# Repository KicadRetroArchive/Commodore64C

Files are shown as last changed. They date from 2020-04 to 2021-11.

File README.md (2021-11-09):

# Commodore 64C KiCad schematics

This project contains a series of schematics and PCB designs for the
Commodore 64C (aka C64-E) personal computer, redrawn in [KiCad](https://kicad.org/).

The schematic was extracted from images available from
[Bo Zimmerman's FTP site](http://www.zimmers.net/anonftp/pub/cbm/schematics/computers/c64/index.html).

The images are also available in the documentation directory.

The project is structured in three main folders:

- [250469-RevA](250469-RevA) - Revision A of the motherboard. This version is also known as
  _Short Board_ and sports the 64 pin _"Super PLA"_ (code 251715-01).
- [250469-RevB](250469-RevB) - Revision B of the motherboard. This version has
  a more advanced version of the Super PLA (code 252535-01) that integrates the Color RAM.
- [docs](docs) - Documentation.
- [libs](libs) - Project's specific KiCad libraries.

## References

- Schematics from [Zimmers FTP site](http://www.zimmers.net/anonftp/pub/cbm/schematics/computers/c64/index.html).
- [C64C Service Manual](http://www.zimmers.net/anonftp/pub/cbm/schematics/computers/c64/servicemanuals/C64-C64C_Service_Manual_314001-03_%281992_Mar%29.pdf).
- [Hardware information](https://www.c64-wiki.com/wiki/Portal:Hardware) from the C64-Wiki.

## Differences

While designing the schematics, I decided to consider the availability of all the
components used as a top priority. While there's little I can do for many of the
ICs, many other components can still be sourced from distributors today.

A few regular components are, however, impossible to find now. In these cases
I replaced them with the closest substitute I could find that is widely available.
These components are different from the originals:

- `CR2`: Diode Rectifier Bridge
- `L1`: Line Filter, 8 terminals
- `Y1`: Crystal
- `L3,L4`: RF Choke Coils
- Some transistors and diodes

## KiCad libraries

Both subprojects use two KiCad set of libraries:

- The [KiCad Retro Library](https://github.com/KicadRetroArchive/kicad-retro-library).
- Project-specific libraries located in the [libs](libs) directory.
  - `250469-01.lib` - C64C specific symbols.
  - `250469-01.pretty` - C64C specific footprints.

> The project-specific libraries are located in a directory **above** the actual
> KiCad project. They are referenced through the `KIPRJMOD` environment variable
> in this way: `"${KIPRJMOD}/../libs/<name of library>"`.

## Credits

This project has been heavily inspired by these awesome projects:

- [LittleSixteen](https://github.com/SukkoPera/LittleSixteen) - Clone of the Commodore 16 by [@SukkoPera](https://github.com/SukkoPera).
- [Commodore-Plus4](https://github.com/StormTrooper/Commodore-Plus4) - Clone of the Commodore Plus 4 by [@StormTrooper](https://github.com/StormTrooper).
- [KU-14194HB-RevB-KiCad](https://github.com/bwack/KU-14194HB-RevB-KiCad) - Clone of the Commodore 64, Assy KU-14194HB-RevB by [@bwack](https://github.com/bwack).

## Contributing

We gladly accept contributions via GitHub pull requests. Please see
[CONTRIBUTING.md](CONTRIBUTING.md) for more details.

## License

Original schematic drawings and service manual are &copy; Commodore Electronics Ltd.

All KiCad design files are copyright &copy; 2020 Andrea Cisternino.

This project is Open Hardware licensed under the
[CERN-OHL-S v2](https://ohwr.org/project/cernohl/wikis/Documents/CERN-OHL-version-2)
license.

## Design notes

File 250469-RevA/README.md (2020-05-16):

# Assembly 250469 Rev. A

Original board:

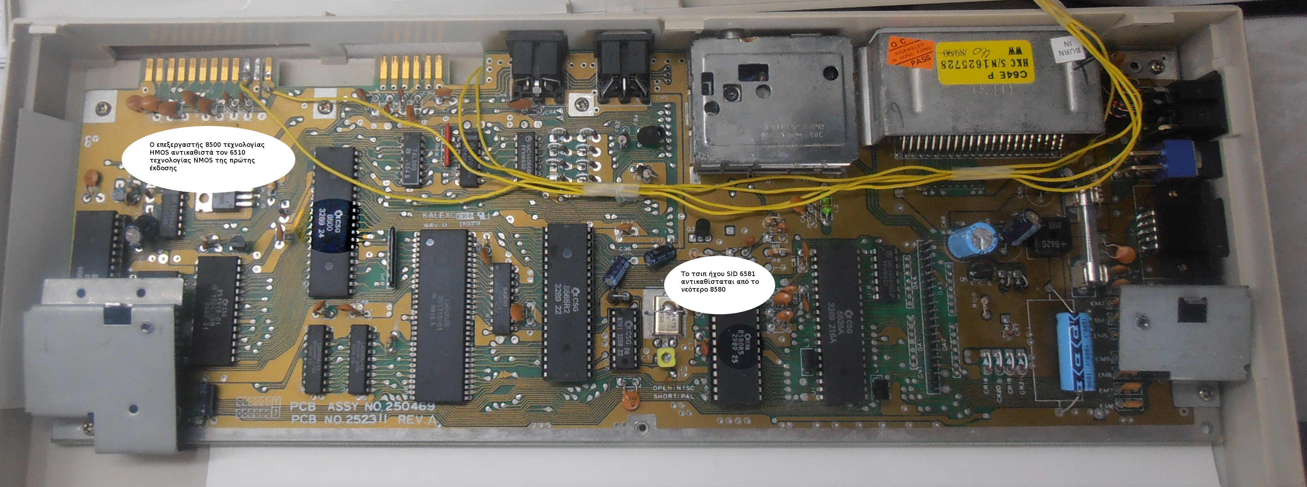
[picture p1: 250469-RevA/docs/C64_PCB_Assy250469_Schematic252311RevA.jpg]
250469 Rev. A board


(_From the [C64-Wiki](https://www.c64-wiki.com/wiki/Motherboard)_)

## Files

- Schematics in PDF: [C64C-250469-01-A.pdf](C64C-250469-01-A.pdf)
- Complete BOM in LibreOffice Calc format, including part numbers from Digi-Key and Mouser
  [C64C-250469-01-A.ods](C64C-250469-01-A.ods)

## Status

I am quite confident that the schematic is stable and bug-free.

**Good News!** I acquired a spare motherboard that matches exactly this revision.
With this example in my hand, I corrected all dimensional errors in the PCB.
I also placed with great precision all the external connectors.
Now work on routing the PCB can begin!

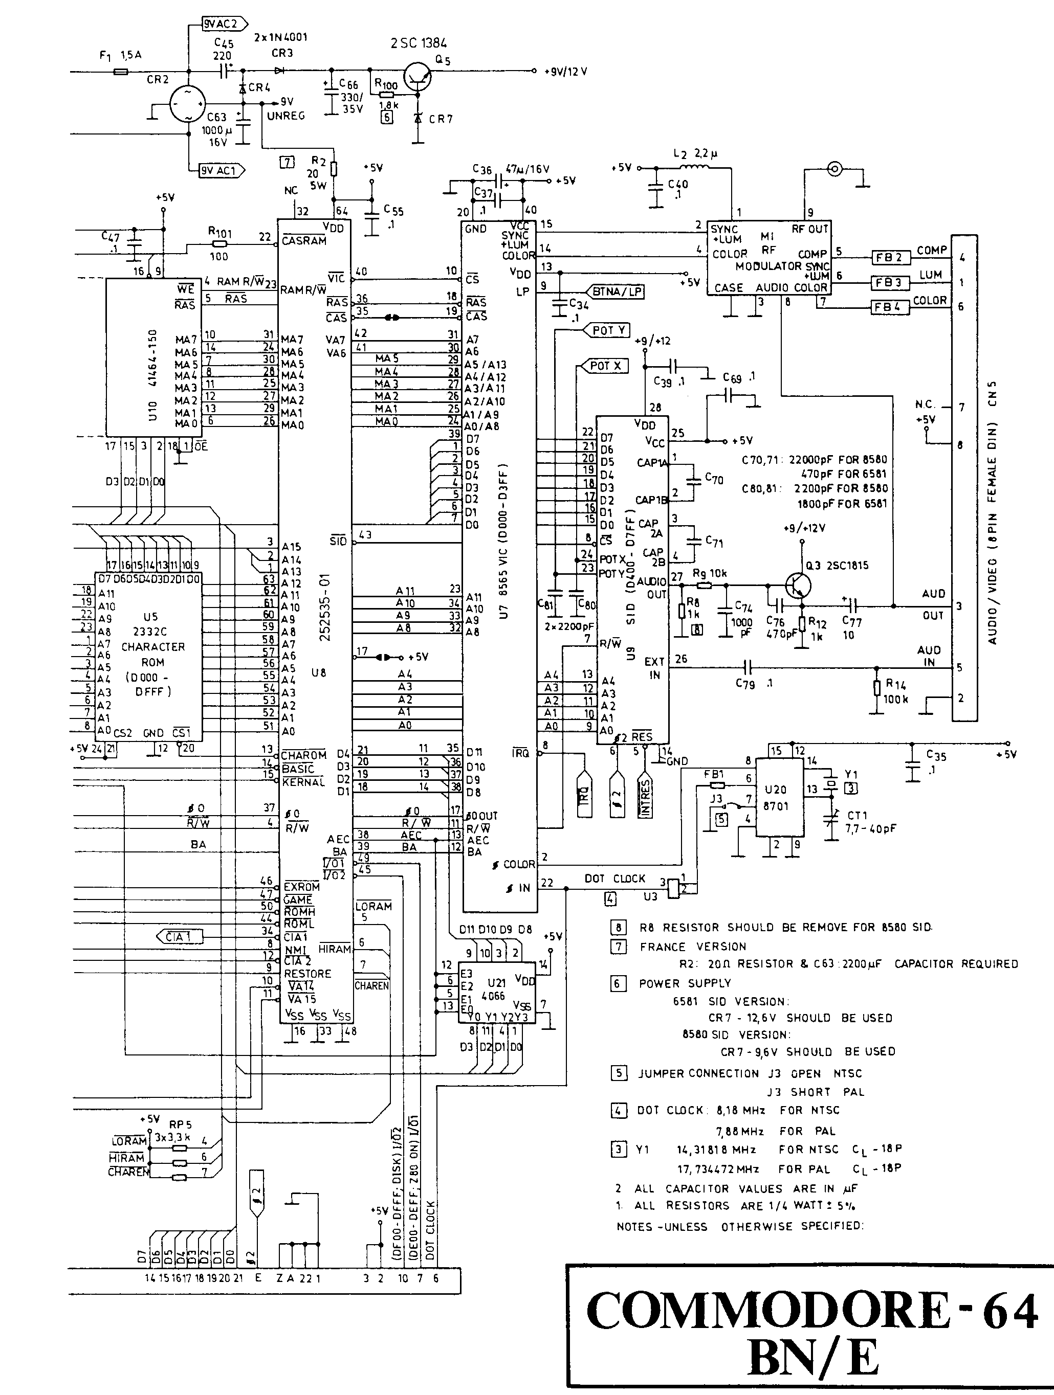
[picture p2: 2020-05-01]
docs/originals/250469-rev.B-right-corrected.png

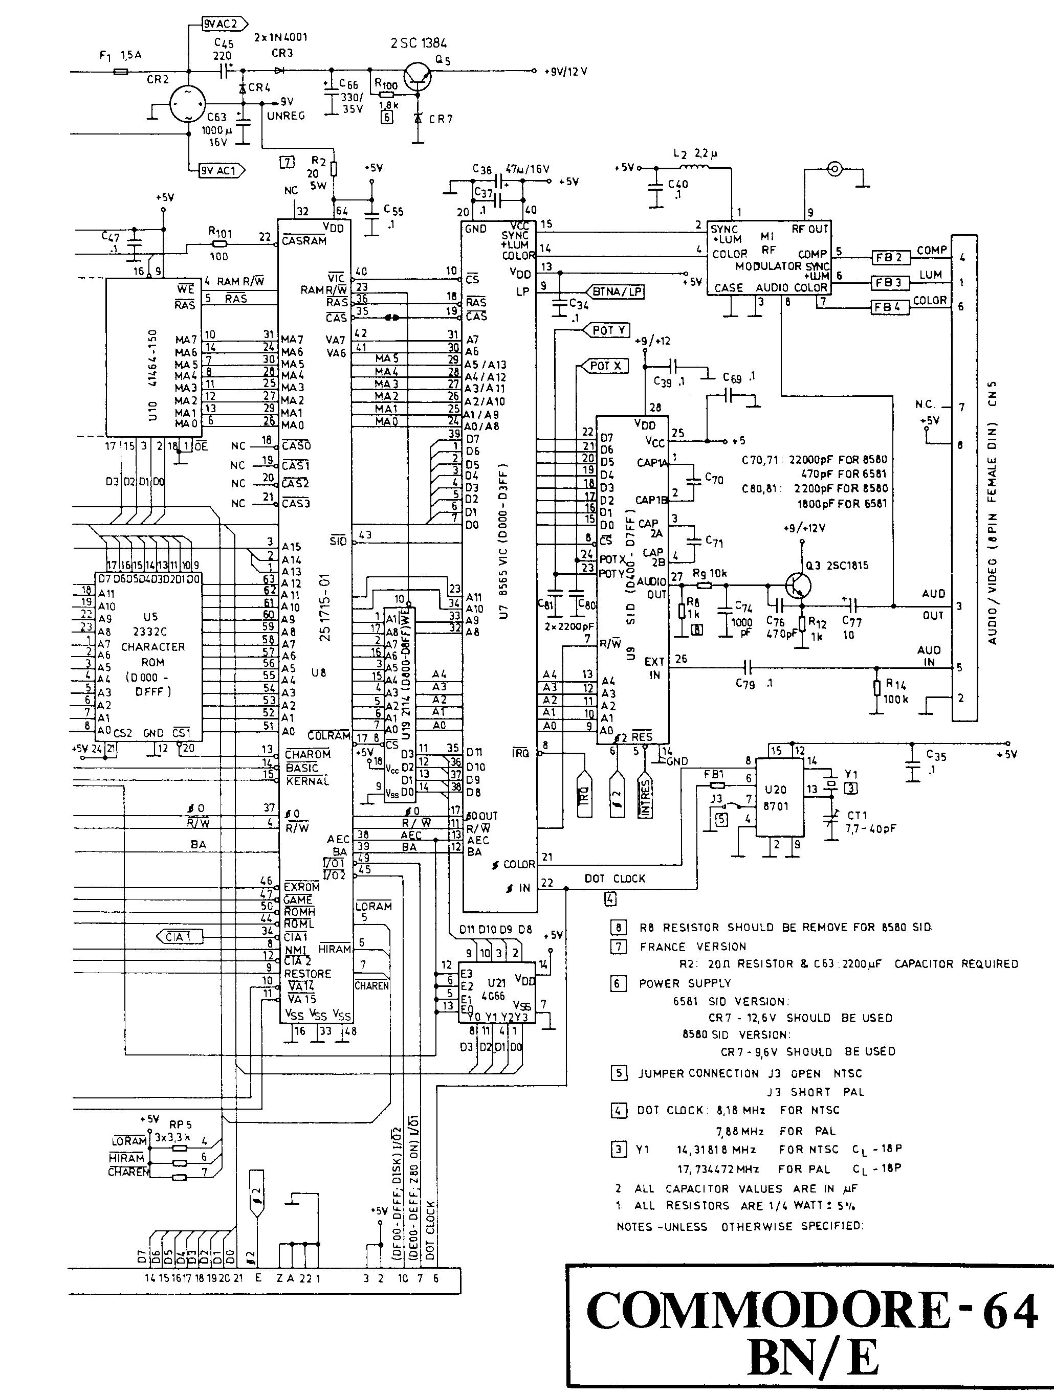
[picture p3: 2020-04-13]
docs/originals/250469-rev.A-right.png

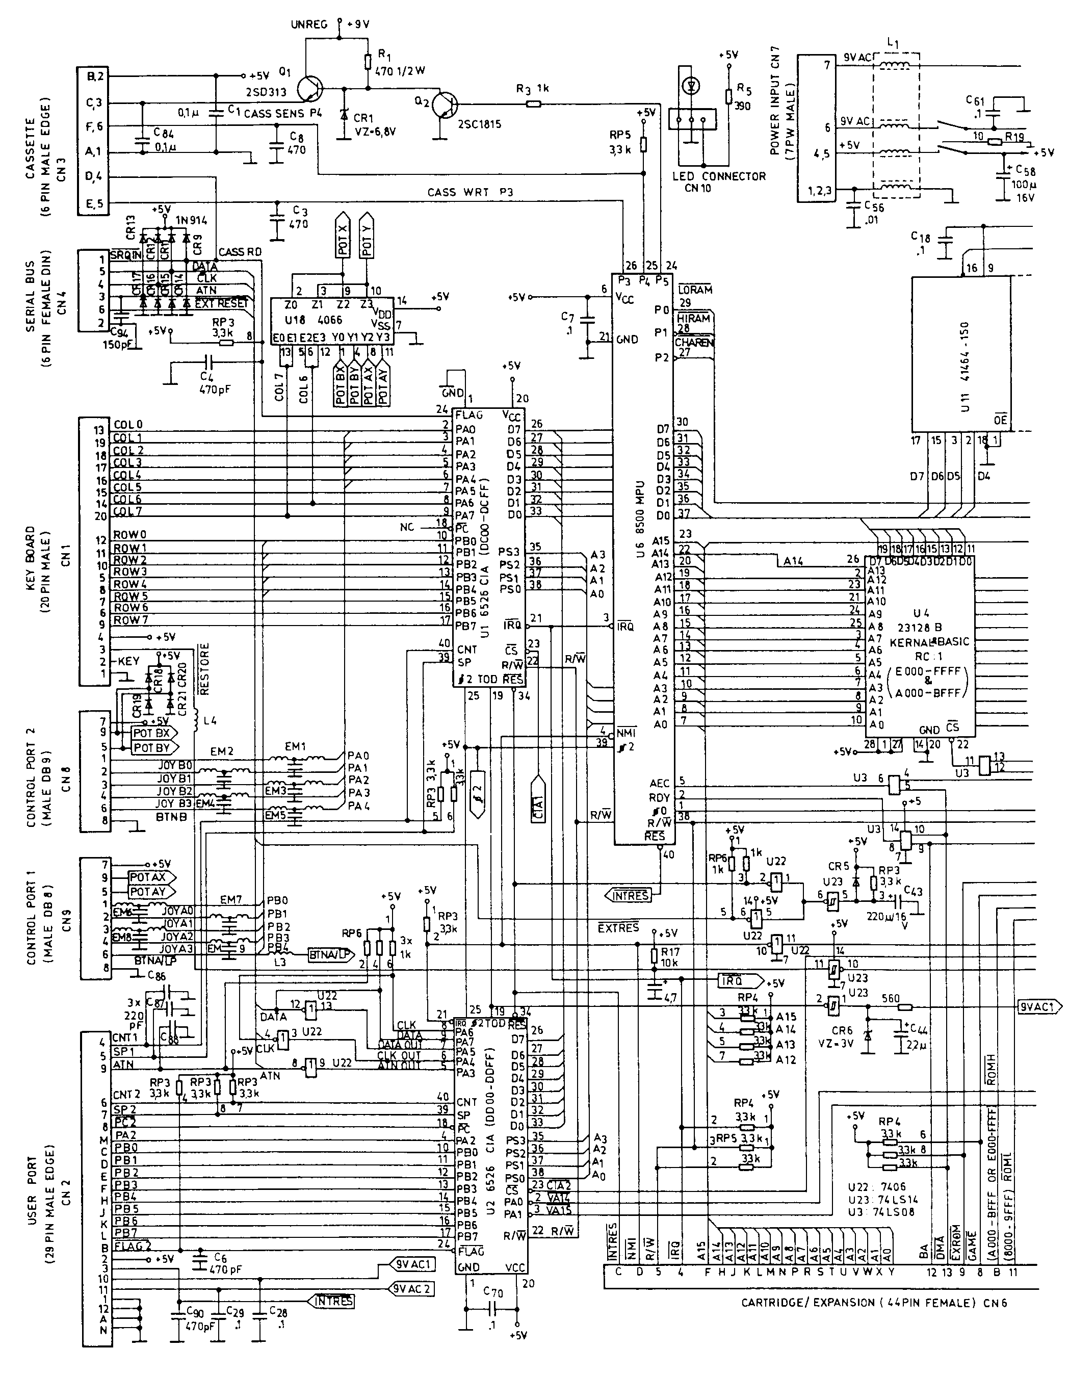
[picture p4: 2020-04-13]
docs/originals/250469-rev.A-left.png

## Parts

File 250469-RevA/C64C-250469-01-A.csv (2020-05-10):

Source: | /home/andrea/Development/github/Commodore64C/250469-RevA/C64C-250469-01-A.sch
Date: | Sun 10 May 2020 06:31:55 PM CEST
Tool: | Eeschema 5.1.5
Generator: | /home/andrea/Apps/kicad/plugins/bom_csv_sc_grouped_by_value_with_fp.py
Component Count: | 131
Ref | Qnty | Value | Cmp name | Footprint | Description | Vendor
C1, C7, C28, C29, C30, C34, C35, C37, C39, C40, C47, C48, C55, C56, C61, C69, C79, C84, | 18 | 0.1u | C | Capacitor_THT:C_Disc_D4.7mm_W2.5mm_P5.00mm | Unpolarized capacitor
C2, C3, C4, C6, C76, C90, | 6 | 470p | C | Capacitor_THT:C_Disc_D4.7mm_W2.5mm_P5.00mm | Unpolarized capacitor
C36, | 1 | 47u/16V | CP | Capacitor_THT:CP_Radial_D8.0mm_P5.00mm | Polarized capacitor
C43, | 1 | 220u | CP | Capacitor_THT:CP_Radial_D8.0mm_P5.00mm | Polarized capacitor
C44, | 1 | 2.2u | CP | Capacitor_THT:CP_Radial_D8.0mm_P5.00mm | Polarized capacitor
C58, | 1 | 100u/16V | CP | Capacitor_THT:CP_Radial_D10.0mm_P5.00mm | Polarized capacitor
C59, | 1 | 4.7u | CP | Capacitor_THT:CP_Radial_D8.0mm_P5.00mm | Polarized capacitor
C63, | 1 | 1000u/16V | CP | Capacitor_THT:CP_Axial_L30.0mm_D15.0mm_P35.00mm_Horizontal | Polarized capacitor
C65, | 1 | 220u | CP | Capacitor_THT:CP_Radial_D10.0mm_P5.00mm | Polarized capacitor
C66, | 1 | 330u/35V | CP | Capacitor_THT:CP_Radial_D12.5mm_P5.00mm | Polarized capacitor
C70, C71, | 2 | 22n | C | Capacitor_THT:C_Disc_D4.7mm_W2.5mm_P5.00mm | Unpolarized capacitor
C74, | 1 | 1000p | C | Capacitor_THT:C_Disc_D4.7mm_W2.5mm_P5.00mm | Unpolarized capacitor
C77, | 1 | 10u | CP | Capacitor_THT:CP_Radial_D10.0mm_P5.00mm | Polarized capacitor
C80, C81, | 2 | 2200p | C | Capacitor_THT:C_Disc_D4.7mm_W2.5mm_P5.00mm | Unpolarized capacitor
C86, C87, C88, | 3 | 220p | C | Capacitor_THT:C_Disc_D4.7mm_W2.5mm_P5.00mm | Unpolarized capacitor
C94, | 1 | 150p | C | Capacitor_THT:C_Disc_D4.7mm_W2.5mm_P5.00mm | Unpolarized capacitor
CB1, | 1 | SW_DPDT | SW_DPDT | 250469-01:RockerSwitch_CuK_DPDT_E201J1AV2 | Rocker Switch, dual pole double throw, on-on
CT1, | 1 | 7.7-40p | CTRIM | krl_Capacitor_THT:C_Trimmer_JML_JML06_P5mm | Trimmable capacitor
D1, | 1 | RD6.8EB | RD6.8EB | Diode_THT:D_DO-35_SOD27_P7.62mm_Horizontal | 500mW Zener Diode, 6.8V, DO-35
D2, | 1 | 2W02G-E4/51 | D_Bridge_+A-A | Diode_THT:Diode_Bridge_Round_D9.8mm | Diode bridge, +ve/AC/-ve/AC
D3, D4, | 2 | 1N4001 | 1N4001 | Diode_THT:D_DO-41_SOD81_P5.08mm_Vertical_KathodeUp | 50V 1A General Purpose Rectifier Diode, DO-41
D5, D9, D11, D12, D13, D14, D15, D16, D17, D18, D19, D20, D21, | 13 | 1N914 | 1N914 | Diode_THT:D_DO-35_SOD27_P5.08mm_Vertical_KathodeUp | 100V 0.3A Small Signal Fast Switching Diode, DO-35
D6, | 1 | RD3.0EB1 | RD3.0EB1 | Diode_THT:D_DO-35_SOD27_P5.08mm_Vertical_KathodeUp | 500mW Zener Diode, 3V, DO-35
D7, | 1 | RD10ESB2 | RD10ESB2 | Diode_THT:D_DO-34_SOD68_P5.08mm_Vertical_KathodeUp | 400mW Zener Diode, 10V, DO-34
F1, | 1 | 1.5A | Fuse | 250469-01:Fuseclip_Cylinder-6.3x32mm | Fuse
FB1, | 1 | 2 Turns | Ferrite_Bead | 250469-01:L_Axial_Dual_L7.0mm_D3.3mm_P5.08mm_Vertical | Ferrite bead
FB2, FB3, FB4, | 3 | Ferrite_Bead_Small | Ferrite_Bead_Small | Inductor_THT:L_Axial_L7.0mm_D3.3mm_P5.08mm_Vertical_Fastron_MICC | Ferrite bead, small symbol
FL1, FL2, FL3, FL4, FL5, FL6, FL7, FL8, FL9, | 9 | 270p | EMI_Filter_LCL | krl_Filter:LCL-Filter_2.8x8.5mm_P2.5mm | EMI T-filter (LCL)
J1, | 1 | Conn_01x20_Male | Conn_01x20_Male | Connector_PinHeader_2.54mm:PinHeader_1x20_P2.54mm_Vertical | Generic connector, single row, 01x20, script generated (kicad-library-utils/schlib/autogen/connector/)
J2, | 1 | Conn_02x12_Edge | Conn_02x12_Edge | 250469-01:Connector_Edge_2x12_P3.96mm | Edge connector, double side, 02x12
J3, | 1 | Conn_02x6_Edge | Conn_02x6_Edge | 250469-01:Connector_Edge_2x6_P3.96mm | Edge connector, double side, connected sides, 02x6
J4, | 1 | DIN-6 | DIN-6 | krl_Connector_DIN:CUI-Devices_SDS-60J_DIN-6_Circular | 6-pin DIN connector
J5, | 1 | DIN-8 | DIN-8 | krl_Connector_DIN:CUI-Devices_SDS-80J_DIN-8_Circular | 8-pin DIN connector
J6, | 1 | Conn_02x22_Edge_Female | Conn_02x22_Edge_Female | 250469-01:Sullins_EBC22DRAN | Generic connector, double row, 02x22, edge, female
J7, | 1 | DIN-7 | DIN-7 | krl_Connector_DIN:CUI-Devices_SDS-70J_DIN-7_Circular | 7-pin DIN connector
J8, J9, | 2 | DB9_Female | DB9_Female | 250469-01:Kycon_K22X-E9P-N_DSUB-9_Male_Horizontal | 9-pin female D-SUB connector
J10, | 1 | LED | Conn_01x03 | Connector_PinHeader_2.54mm:PinHeader_1x03_P2.54mm_Vertical | Generic connector, single row, 01x03, script generated (kicad-library-utils/schlib/autogen/connector/)
JP3, | 1 | Jumper | Jumper | Connector_PinHeader_2.54mm:PinHeader_1x02_P2.54mm_Vertical | Jumper, normally closed
L1, | 1 | CM4545Z131B-10 | CM4545Z131B-10 | krl_Filter:Laird_CM4545Z131B-10 | Quadruple Coupled inductor with ferrite core
L2, | 1 | 2.2u | L | Inductor_THT:L_Axial_L9.5mm_D4.0mm_P15.24mm_Horizontal_Fastron_SMCC | Inductor
L3, L4, | 2 | 10uH | L | 250469-01:L_Radial_L7.5mm_W3mm_P5.00mm_Kemet_SBT-02 | Inductor
M1, | 1 | RF_Modulator | RF_Modulator | 250469-01:RF_Modulator | C64C RF Modulator
Q1, | 1 | 2SD313 | 2SD313E | Package_TO_SOT_THT:TO-220-3_Horizontal_TabDown | 3A Ic, 60V Vce, High Voltage Power NPN Transistor, TO-220
Q2, Q3, | 2 | 2SC1815 | 2SC1815 | Package_TO_SOT_THT:TO-92_Inline | 0.15A Ic, 50V Vce, Low Noise Audio NPN Transistor, TO-92
Q5, | 1 | 2SC1384 | 2SC1384 | Package_TO_SOT_THT:TO-92_Inline | 1A Ic, 50V Vce, NPN Transistor, TO-92
R1, | 1 | 470 | R | Resistor_THT:R_Axial_DIN0309_L9.0mm_D3.2mm_P15.24mm_Horizontal | Resistor
R3, R8, R12, | 3 | 1k | R | Resistor_THT:R_Axial_DIN0207_L6.3mm_D2.5mm_P5.08mm_Vertical | Resistor
R5, | 1 | 390 | R | Resistor_THT:R_Axial_DIN0207_L6.3mm_D2.5mm_P5.08mm_Vertical | Resistor
R9, R17, | 2 | 10k | R | Resistor_THT:R_Axial_DIN0207_L6.3mm_D2.5mm_P5.08mm_Vertical | Resistor
R14, | 1 | 100k | R | Resistor_THT:R_Axial_DIN0207_L6.3mm_D2.5mm_P5.08mm_Vertical | Resistor
R16, | 1 | 560 | R | Resistor_THT:R_Axial_DIN0207_L6.3mm_D2.5mm_P5.08mm_Vertical | Resistor
R19, | 1 | 10 | R | Resistor_THT:R_Axial_DIN0309_L9.0mm_D3.2mm_P15.24mm_Horizontal | Resistor
R100, | 1 | 1.8k | R | Resistor_THT:R_Axial_DIN0207_L6.3mm_D2.5mm_P5.08mm_Vertical | Resistor
R101, | 1 | 100 | R | Resistor_THT:R_Axial_DIN0207_L6.3mm_D2.5mm_P5.08mm_Vertical | Resistor
RN3, RN5, | 2 | 3.3k | R_Network07 | Resistor_THT:R_Array_SIP8 | 7 resistor network, star topology, bussed resistors, small symbol
RN4, | 1 | 3.3k | R_Network08 | Resistor_THT:R_Array_SIP9 | 8 resistor network, star topology, bussed resistors, small symbol
RN6, | 1 | 1k | R_Network05 | Resistor_THT:R_Array_SIP6 | 5 resistor network, star topology, bussed resistors, small symbol
U1, U2, | 2 | 6526A | 6526A | Package_DIP:DIP-40_W15.24mm_Socket | CIA Complex Interface Adapter, NMOS, 2MHz, DIP-40
U3, | 1 | 74LS08 | 74LS08 | Package_DIP:DIP-14_W7.62mm_Socket | Quad And2
U4, | 1 | 23128 | 23128 | Package_DIP:DIP-28_W15.24mm_Socket | 16K x 8 Mask ROM, DIP-28
U5, | 1 | 2332 | 2332 | Package_DIP:DIP-24_W15.24mm_Socket | 4K x 8 Mask ROM, 450ns, DIP-24
U6, | 1 | 8500 | 8500 | Package_DIP:DIP-40_W15.24mm_Socket | CPU Central Processing Unit with I/O, 8-bit, HMOS, 1 MHz, DIP-40
U7, | 1 | 8565R2 | 8565R2 | Package_DIP:DIP-40_W15.24mm_Socket | VIC-II Video Interface Chip II, PAL, HMOS, DIP-40
U8, | 1 | 251715-01 | 251715-01 | krl_Package_SPDIP:SPDIP-64_W19.05mm_Socket_LongPads | C64C Memory Controller (SuperPLA), SPDIP-64
U9, | 1 | 8580R5 | 8580R5 | Package_DIP:DIP-28_W15.24mm_Socket | Video Interface Chip II - C64 - PAL, DIP-28
U10, U11, | 2 | 41464 | 41464 | Package_DIP:DIP-18_W7.62mm_Socket | 64K x 4 Dynamic NMOS RAM, DIP-18
U18, U21, | 2 | 4066 | 4066 | Package_DIP:DIP-14_W7.62mm_Socket | Quad Analog Switches
U19, | 1 | 2114 | 2114 | Package_DIP:DIP-18_W7.62mm_Socket | 1K x 4 Static RAM, DIP-18
U20, | 1 | 8701 | 8701 | Package_DIP:DIP-16_W7.62mm_Socket | C64 Clock Generator, DIP-16
U22, | 1 | 7416 | 7416 | Package_DIP:DIP-14_W7.62mm_Socket | TTL Hex inverter buffers/drivers with open-collector high-voltage outputs
U23, | 1 | 74LS14 | 74LS14 | Package_DIP:DIP-14_W7.62mm_Socket | Hex inverter schmitt trigger
Y1, | 1 | Crystal | Crystal | Crystal:Crystal_HC49-U_Vertical | Two pin crystal

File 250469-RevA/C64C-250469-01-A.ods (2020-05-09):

Ref | Qnty | Value | Cmp name | Footprint | Description | Vendor | MPM | DigiKey | Mouser
C1, C7, C28, C29, C30, C34, C35, C37, C39, C40, C47, C48, C55, C56, C61, C69, C79, C84, | 18 | 0.1u | C | Capacitor_THT:C_Disc_D4.7mm_W2.5mm_P5.00mm | Unpolarized capacitor | Vishay | K104K15X7RF5TH5 | BC1101CT-ND | 594-K104K15X7RF5TH5
C2, C3, C4, C6, C76, C90, | 6 | 470p | C | Capacitor_THT:C_Disc_D4.7mm_W2.5mm_P5.00mm | Unpolarized capacitor | Murata | RDER71H471K0K1H03B | 490-8846-ND | 81-RDER71H471K0K1H3B
C36, | 1 | 47u/16V | CP | Capacitor_THT:CP_Radial_D8.0mm_P5.00mm | Polarized capacitor | Panasonic | ECA-1CM470B | P19514CT-ND | 667-ECA-1CM470B
C43, | 1 | 220u/16V | CP | Capacitor_THT:CP_Radial_D8.0mm_P5.00mm | Polarized capacitor | Panasonic | EEU-FR1C221B | P15337CT-ND | 667-EEU-FR1C221B
C44, | 1 | 2.2u/50V | CP | Capacitor_THT:CP_Radial_D8.0mm_P5.00mm | Polarized capacitor | Panasonic | ECE-A1HKS2R2B | P19507CT-ND | 667-ECE-A1HKS2R2B
C58, | 1 | 100u/16V | CP | Capacitor_THT:CP_Radial_D10.0mm_P5.00mm | Polarized capacitor | Panasonic | EEU-FR1C101B | P15330CT-ND | 667-EEU-FR1C101B
C59, | 1 | 4.7u/25V | CP | Capacitor_THT:CP_Radial_D8.0mm_P5.00mm | Polarized capacitor | Nichicon | UVR1V4R7MDD1TA | 493-17443-1-ND | 647-UVR1V4R7MDD1TA
C63, | 1 | 1000u/16V | CP | Capacitor_THT:CP_Axial_L30.0mm_D15.0mm_P35.00mm_Horizontal | Polarized capacitor |  |  | 108TTA025M | MAL202117102E3
C65, | 1 | 220u/25V | CP | Capacitor_THT:CP_Radial_D12.5mm_P5.00mm | Polarized capacitor | Nichicon | UHE1H221MPD | 493-1609-ND | 647-UHE1H221MPD
C66, | 1 | 330u/35V | CP | Capacitor_THT:CP_Radial_D12.5mm_P5.00mm | Polarized capacitor | Panasonic | EEU-FM1H471 | P12400-ND | 667-EEU-FM1H471
C70, C71, | 2 | 22n/50V | C | Capacitor_THT:C_Disc_D4.7mm_W2.5mm_P5.00mm | Unpolarized capacitor | Vishay | K223K15X7RF5UH5 | BC5231CT-ND | 594-K223K15X7RF5UH5
C74, | 1 | 1000p/50V | C | Capacitor_THT:C_Disc_D4.7mm_W2.5mm_P5.00mm | Unpolarized capacitor | Vishay | K102K15X7RF5TH5 | BC1089CT-ND | 594-K102K15X7RF5TH5
C77, | 1 | 10u/25V | CP | Capacitor_THT:CP_Radial_D10.0mm_P5.00mm | Polarized capacitor | Nichicon | UCY2G100MPD | 493-13387-ND | 647-UCY2G100MPD
C80, C81, | 2 | 2200p/25V | C | Capacitor_THT:C_Disc_D4.7mm_W2.5mm_P5.00mm | Unpolarized capacitor | Vishay | K222K10X7RF5UH5 | BC2675CT-ND | 594-K222K10X7RF5UH5
C86, C87, C88, | 3 | 220p/50V | C | Capacitor_THT:C_Disc_D4.7mm_W2.5mm_P5.00mm | Unpolarized capacitor | Vishay | K221K15X7RF5TH5 | BC1085CT-ND | 594-K221K15X7RF5TH5
C94, | 1 | 150p/50V | C | Capacitor_THT:C_Disc_D4.7mm_W2.5mm_P5.00mm | Unpolarized capacitor | Vishay | K151J15C0GF5TH5 | BC1043CT-ND | 594-K151J15C0GF5TH5
CB1, | 1 | SW_DPDT | SW_DPDT | 250469-01:RockerSwitch_CuK_DPDT_E201J1AV2 | Rocker Switch, dual pole double throw, on-on | C&K | E201J1AV2QE2 | CKN2075-ND | 611-E201-005
CT1, | 1 | 7.7-40p | CTRIM | Capacitor_SMD:C_Trimmer_Voltronics_JZ | Trimmable capacitor | Knowles | JZ400 | 1674-1006-1-ND | 768-JZ400
D1, | 1 | RD6.8EB | RD6.8EB | Diode_THT:D_DO-35_SOD27_P7.62mm_Horizontal | 500mW Zener Diode, 6.8V, DO-35 | ON Semiconductor | BZX79C6V8 | BZX79C6V8-ND | 512-BZX79C6V8
D2, | 1 | 2W02G-E4/51 | D_Bridge_+A-A | Diode_THT:Diode_Bridge_Round_D9.8mm | Bridge Rectifier 1 Phase, 200V, 2A, WOG | Vishay | 2W02G-E4/51 | 2W02G-E4/51GI-ND | 625-2W02G-E4
D3, D4, | 2 | 1N4001 | 1N4001 | Diode_THT:D_DO-41_SOD81_P5.08mm_Vertical_KathodeUp | 50V 1A General Purpose Rectifier Diode, DO-41 | Comchip Technology | 1N4001-G | 641-1310-1-ND | 750-1N4001-G
D5, D9, D11, D12, D13, D14, D15, D16, D17, D18, D19, D20, D21, | 13 | 1N914 | 1N914 | Diode_THT:D_DO-35_SOD27_P5.08mm_Vertical_KathodeUp | 100V 0.3A Small Signal Fast Switching Diode, DO-35 | ON Semiconductor | 1N914TR | 1N914CT-ND | 512-1N914TR
D6, | 1 | RD3.0EB1 | RD3.0EB1 | Diode_THT:D_DO-35_SOD27_P5.08mm_Vertical_KathodeUp | 500mW Zener Diode, 3V, DO-35 | ON Semiconductor | 1N5225B | 1N5225B-ND | 512-1N5225B
D7, | 1 | RD10ESB2 | RD10ESB2 | Diode_THT:D_DO-34_SOD68_P5.08mm_Vertical_KathodeUp | 400mW Zener Diode, 10V, DO-34 | ON Semiconductor | BZX79C10 | BZX79C10-ND | 512-BZX79C10
F1, | 1 | 1.5A | Fuse | 250469-01:Fuseclip_Cylinder-6.3x32mm | Fuse
F1A, F1B, | 2 | 3529 | Fuse Clip |  | Fuse Clip 15A PCB | Keystone Electronics | 3529 | 36-3529-ND | 534-3529
FB1, | 1 | 2 Turns | Ferrite_Bead | 250469-01:L_Axial_Dual_L7.0mm_D3.3mm_P5.08mm_Vertical | Ferrite bead | Fair-Rite | 2761002112 | 1934-1424-1-ND | 623-2761002112LF
FB2, FB3, FB4, | 3 | Ferrite_Bead_Small | Ferrite_Bead_Small | Inductor_THT:L_Axial_L7.0mm_D3.3mm_P5.08mm_Vertical_Fastron_MICC | Ferrite bead, small symbol | Fair-Rite | 2761001112 | 1934-1423-1-ND | 623-2761001112
FL1, FL2, FL3, FL4, FL5, FL6, FL7, FL8, FL9, | 9 | 270p | EMI_Filter_LCL | krl_Filter:LCL-Filter_2.8x8.5mm_P2.5mm | EMI T-filter (LCL) | Bourns Inc. | EMI271T-RC | M9940CT-ND | 652-EMI271T-RC | Alternative: Murata DSS1NB32A271Q91A
J1, | 1 | Conn_01x20_Male | Conn_01x20_Male | Connector_PinHeader_2.54mm:PinHeader_1x20_P2.54mm_Vertical | Generic connector, single row, 01x20, script generated (kicad-library-utils/schlib/autogen/connector/)
J2, | 1 | Conn_02x12_Edge | Conn_02x12_Edge | 250469-01:Connector_Edge_2x12_P3.96mm | Edge connector, double side, 02x12
J3, | 1 | Conn_02x6_Edge | Conn_02x6_Edge | 250469-01:Connector_Edge_2x6_P3.96mm | Edge connector, double side, connected sides, 02x6
J4, | 1 | DIN-6 | DIN-6 | krl_Connector_DIN:CUI-Devices_SDS-60J_DIN-6_Circular | 6-pin DIN connector | CUI Devices | SDS-60J | CP-2360-ND | 490-SDS-60J
J5, | 1 | DIN-8 | DIN-8 | krl_Connector_DIN:CUI-Devices_SDS-80J_DIN-8_Circular | 8-pin DIN connector | CUI Devices | SDS-80J | CP-2380-ND | 490-SDS-80J
J6, | 1 | Conn_02x22_Edge_Female | Conn_02x22_Edge_Female | 250469-01:Sullins_EBC22DRAN | Generic connector, double row, 02x22, edge, female | Sullins | EBC22DRAN | EBC22DRAN-ND
J7, | 1 | DIN-7 | DIN-7 | krl_Connector_DIN:CUI-Devices_SDS-70J_DIN-7_Circular | 7-pin DIN connector | CUI Devices | SDS-70J | CP-2370-ND | 490-SDS-70J
J8, J9, | 2 | DB9_Female | DB9_Female | 250469-01:Kycon_K22X-E9P-N_DSUB-9_Male_Horizontal | 9-pin female D-SUB connector | Kycon | K22X-E9P-N | 2092-K22X-E9P-N-ND | 806-K22X-E9P-N-99
J10, | 1 | LED | Conn_01x03 | Connector_PinHeader_2.54mm:PinHeader_1x03_P2.54mm_Vertical | Generic connector, single row, 01x03, script generated (kicad-library-utils/schlib/autogen/connector/)
JP3, | 1 | Jumper | Conn_01x02 | Connector_PinHeader_2.54mm:PinHeader_1x02_P2.54mm_Vertical | Generic connector, single row, 01x02, script generated (kicad-library-utils/schlib/autogen/connector/)
L1, | 1 | CM4545Z131B-10 | CM4545Z131B-10 | krl_Filter:Laird_CM4545Z131B-10 | Quadruple Coupled inductor with ferrite core | Laird | CM4545Z131B-10 | 240-2486-ND | 875-CM4545Z131B-10 | Or 2x RN214-4-02-1M5
L2, | 1 | 2.2u | L | 250469-01:L_Radial_L7.5mm_W3mm_P5.00mm_Kemet_SBT-02 | Inductor | TDK | B78108S1222K000 | 495-5556-1-ND | 871-B78108S1222K
L3, L4, | 2 | 10u | L | 250469-01:L_Radial_L7.5mm_W3mm_P5.00mm_Kemet_SBT-02 | Inductor | Kemet | SBT-0210 | 399-SBT-0210-ND | 80-SBT-0210
M1, | 1 | RF_Modulator | RF_Modulator | 250469-01:RF_Modulator | C64C RF Modulator
Q1, | 1 | 2SD313 | 2SD313E | Package_TO_SOT_THT:TO-220-3_Horizontal_TabDown | 3A Ic, 60V Vce, High Voltage Power NPN Transistor, TO-220 | STMicroelectronics | 2ST31A | 497-11083-5-ND | 511-2ST31A
Q2, Q3, | 2 | 2SC1815 | 2SC1815 | Package_TO_SOT_THT:TO-92_Inline | 0.15A Ic, 50V Vce, Low Noise Audio NPN Transistor, TO-92 | ON Semiconductor | KSC1815YTA | KSC1815YTACT-ND | 512-KSC1815YTA
Q5, | 1 | 2SC1384 | 2SC1384 | Package_TO_SOT_THT:TO-92 | 1A Ic, 50V Vce, NPN Transistor, TO-92 | ON Semiconductor | KSD1616AGBU | KSD1616AGBU-ND | 512-KSD1616AGBU
R1, | 1 | 470 | R | Resistor_THT:R_Axial_DIN0309_L9.0mm_D3.2mm_P15.24mm_Horizontal | Resistor |  |  | CF12JT470RCT-ND | 660-CF1/2CT52R471J
R3, R8, R12, | 3 | 1k | R | Resistor_THT:R_Axial_DIN0207_L6.3mm_D2.5mm_P5.08mm_Vertical | Resistor |  |  | CF14JT1K00CT-ND | 291-1K-RC
R5, | 1 | 390 | R | Resistor_THT:R_Axial_DIN0207_L6.3mm_D2.5mm_P5.08mm_Vertical | Resistor |  |  | CF14JT390RCT-ND | 660-CF1/4C391J
R9, R17, | 2 | 10k | R | Resistor_THT:R_Axial_DIN0207_L6.3mm_D2.5mm_P5.08mm_Vertical | Resistor |  |  | CF14JT10K0CT-ND | 588-OK1035E-R52
R14, | 1 | 100k | R | Resistor_THT:R_Axial_DIN0207_L6.3mm_D2.5mm_P5.08mm_Vertical | Resistor |  |  | CF14JT100KCT-ND | 291-100K-RC
R16, | 1 | 560 | R | Resistor_THT:R_Axial_DIN0207_L6.3mm_D2.5mm_P5.08mm_Vertical | Resistor |  |  | CF14JT560RCT-ND | 660-CF1/4CT52R561J
R19, | 1 | 10 | R | Resistor_THT:R_Axial_DIN0309_L9.0mm_D3.2mm_P15.24mm_Horizontal | Resistor |  |  | CF12JT10R0CT-ND | 588-OL1005E-R52
R100, | 1 | 1.8k | R | Resistor_THT:R_Axial_DIN0207_L6.3mm_D2.5mm_P5.08mm_Vertical | Resistor |  |  | 1.8KQBK-ND | 660-CF1/4C182J
R101, | 1 | 100 | R | Resistor_THT:R_Axial_DIN0207_L6.3mm_D2.5mm_P5.08mm_Vertical | Resistor |  |  | CF14JT100RCT-ND | 291-100-RC
RN3, RN5, | 2 | 3.3k | R_Network07 | Resistor_THT:R_Array_SIP8 | 7 resistor network, star topology, bussed resistors, small symbol | Bourns Inc. | 4608X-101-332LF | 4608X-1-332LF-ND | 652-4608X-1LF-3.3K
RN4, | 1 | 3.3k | R_Network08 | Resistor_THT:R_Array_SIP9 | 8 resistor network, star topology, bussed resistors, small symbol | Bourns Inc. | 4609X-101-332LF | 4609X-101-332LF-ND | 652-4609X-1LF-3.3K
RN6, | 1 | 1k | R_Network05 | Resistor_THT:R_Array_SIP6 | 5 resistor network, star topology, bussed resistors, small symbol | CTS Resistor Products | 77061102P | 770-61-R1KP-ND | 774-77061102P
U1, | 1 | 6526A | 6526A | Package_DIP:DIP-40_W15.24mm_Socket | CIA Complex Interface Adapter, NMOS, 2MHz, DIP-40 |  |  | ED90059-ND | 575-1154764041001000
U2, | 1 | 6526A | 6526A | Package_DIP:DIP-40_W15.24mm_Socket | CIA Complex Interface Adapter, NMOS, 2MHz, DIP-40 |  |  | ED90059-ND | 575-1154764041001000
U3, | 1 | 74LS08 | 74LS08 | Package_DIP:DIP-14_W7.62mm_Socket | Quad And2 |  |  | A120348-ND | 575-1104731441001000
U4, | 1 | 23128 | 23128 | Package_DIP:DIP-28_W15.24mm_Socket | 16K x 8 bit PROM |  |  | 3M5469-ND | 437-1108762841001101
U5, | 1 | 2332 | 2332 | Package_DIP:DIP-24_W15.24mm_Socket | 16K x 8 PROM |  |  | ED3051-5-ND | 575-1104762441001000
U6, | 1 | 8500 | 8500 | Package_DIP:DIP-40_W15.24mm_Socket | CPU Central Processing Unit with I/O, 8-bit, HMOS, 1 MHz, DIP-40 |  |  | ED90059-ND | 575-1154764041001000
U7, | 1 | 8565 | 8565 | Package_DIP:DIP-40_W15.24mm_Socket | VIC-II Video Interface Chip II, PAL, HMOS, DIP-40 |  |  | ED90059-ND | 575-1154764041001000
U8, | 1 | 251715-01 | 251715-01 | krl_Package_SPDIP:SPDIP-64_W19.05mm_LongPads | C64C Memory Controller (SuperPLA), SPDIP-64 |  |  | 1212-1068-ND
U9, | 1 | 8580R5 | 8580R5 | Package_DIP:DIP-28_W15.24mm_Socket | Video Interface Chip II - C64 - PAL, DIP-28 |  |  | 3M5469-ND | 437-1108762841001101
U10, U11, | 2 | 41464 | 41464 | Package_DIP:DIP-18_W7.62mm_Socket | 64K x 4 Dynamic NMOS RAM, DIP-18 |  |  | 1175-1470-ND | 575-1154731841001000
U18, U21, | 2 | 4066 | 4066 | Package_DIP:DIP-14_W7.62mm_Socket | Quad Analog Switches |  |  | A120348-ND | 575-1104731441001000
U19, | 1 | 2114 | 2114 | Package_DIP:DIP-18_W7.62mm_Socket | 1K x 4 Static RAM, DIP-18 |  |  | 1175-1470-ND | 575-1154731841001000
U20, | 1 | 8701 | 8701 | Package_DIP:DIP-16_W7.62mm_Socket | C64 Clock Generator, DIP-16 |  |  | AE10013-ND | 575-1104731641001000
U22, | 1 | 7416 | 7416 | Package_DIP:DIP-14_W7.62mm_Socket | TTL Hex inverter buffers/drivers with open-collector high-voltage outputs |  |  | A120348-ND | 575-1104731441001000
U23, | 1 | 74LS14 | 74LS14 | Package_DIP:DIP-14_W7.62mm_Socket | Hex inverter schmitt trigger |  |  | A120348-ND | 575-1104731441001000
Y1, | 1 | 17.734472 MHz | Crystal | Crystal:Crystal_HC49-U_Vertical | Two pin crystal PAL | IQD | LFXTAL016765Bulk |  | 449-LFXTAL016765BULK
Y1, | 1 | 14.31818 MHz | Crystal | Crystal:Crystal_HC49-U_Vertical | Two pin crystal NTSC | CTS | ATS143B-E | CTX923-ND | 774-ATS143B-E

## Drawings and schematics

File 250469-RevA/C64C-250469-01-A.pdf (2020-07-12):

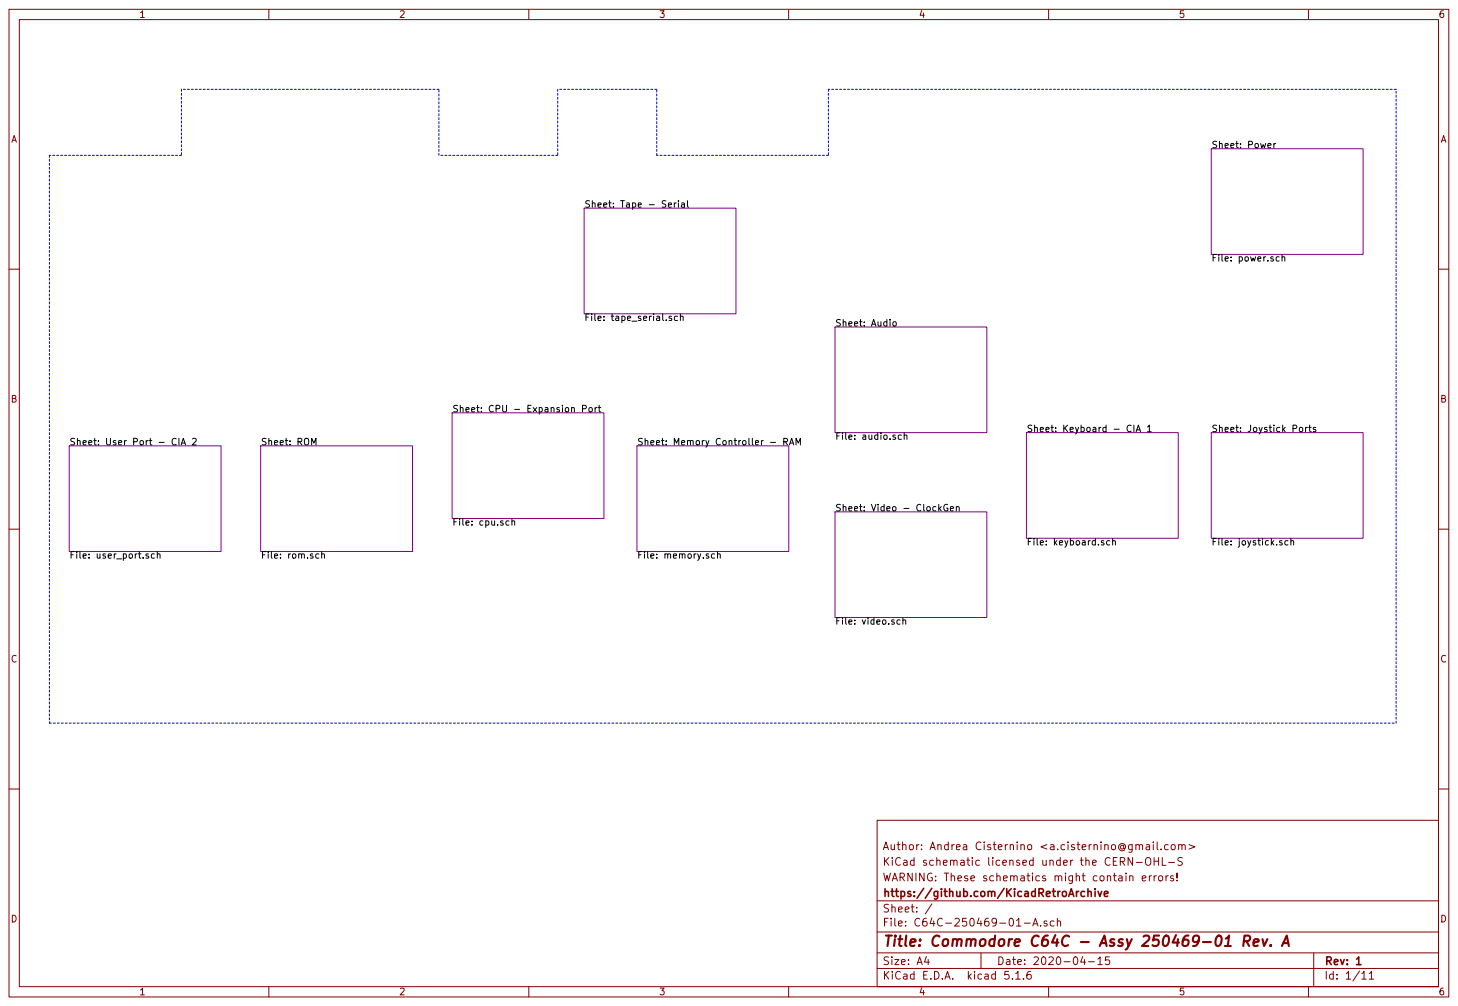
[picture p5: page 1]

File: joystick.sch Sheet: Power File: power.sch

Sheet: Memory Controller - RAM

Author: Andrea Cisternino <a.cisternino@gmail.com>
WARNING: These schematics might contain errors! KiCad schematic licensed under the CERN-OHL-S

File: C64C-250469-01-A.sch Sheet: / https://github.com/KicadRetroArchive

Id: 1/11 Title: Commodore C64C - Assy 250469-01 Rev. A

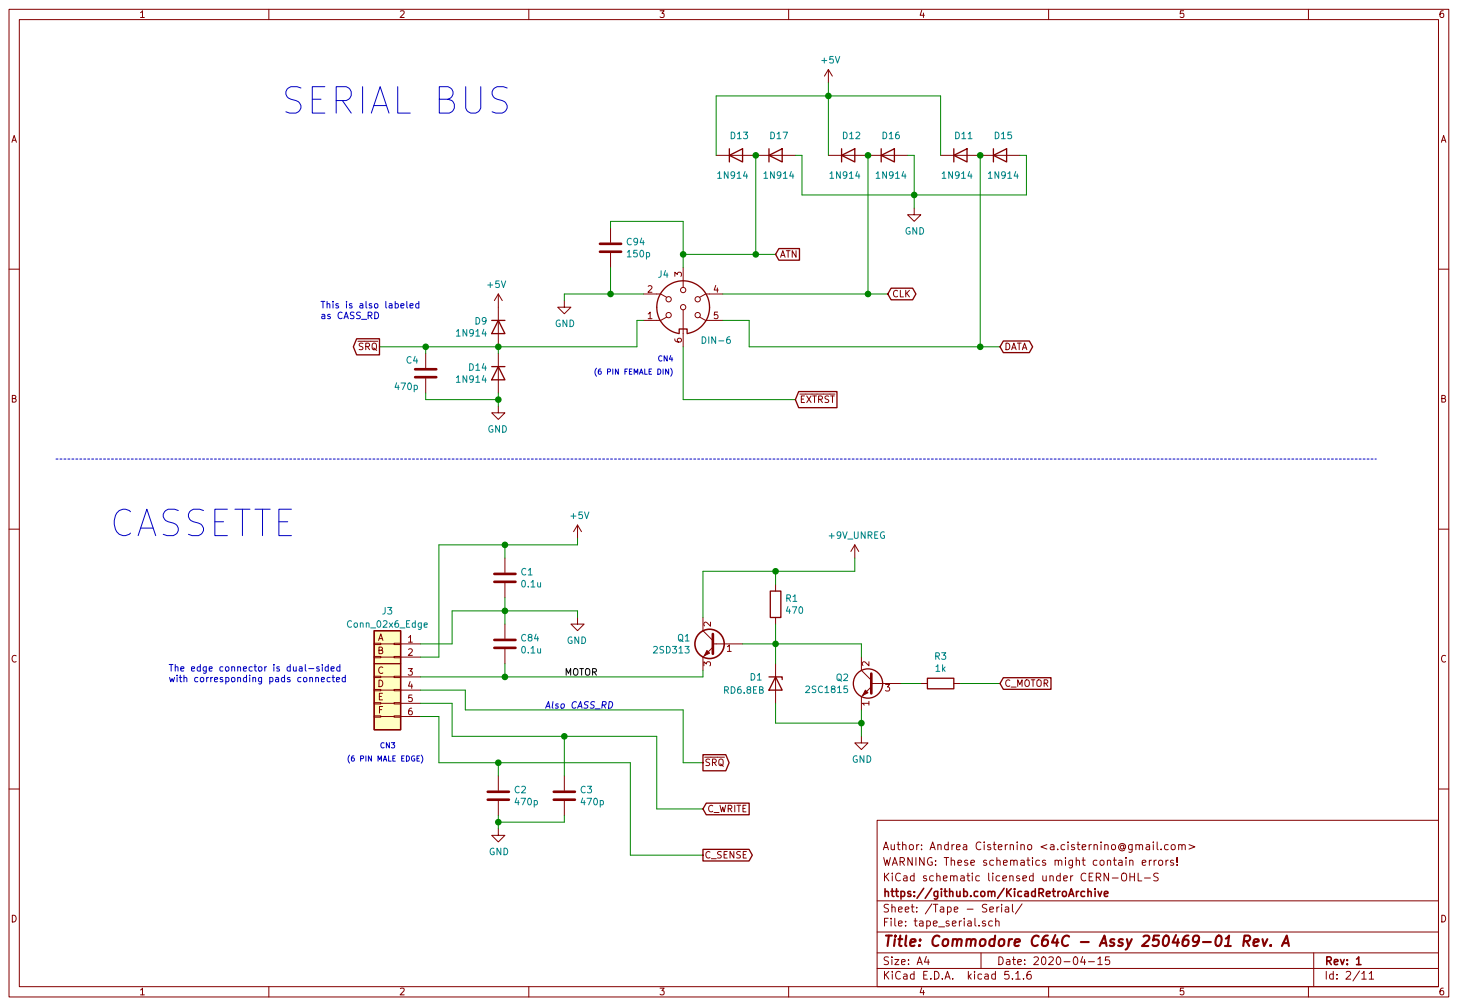
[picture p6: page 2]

(6 PIN FEMALE DIN) This is also labeled
as CASS_RD

(6 PIN MALE EDGE) The edge connector is dual-sided

Author: Andrea Cisternino <a.cisternino@gmail.com>
https://github.com/KicadRetroArchive KiCad schematic licensed under CERN-OHL-S WARNING: These schematics might contain errors!

Sheet: /Tape - Serial/
File: tape_serial.sch
Id: 2/11 Title: Commodore C64C - Assy 250469-01 Rev. A

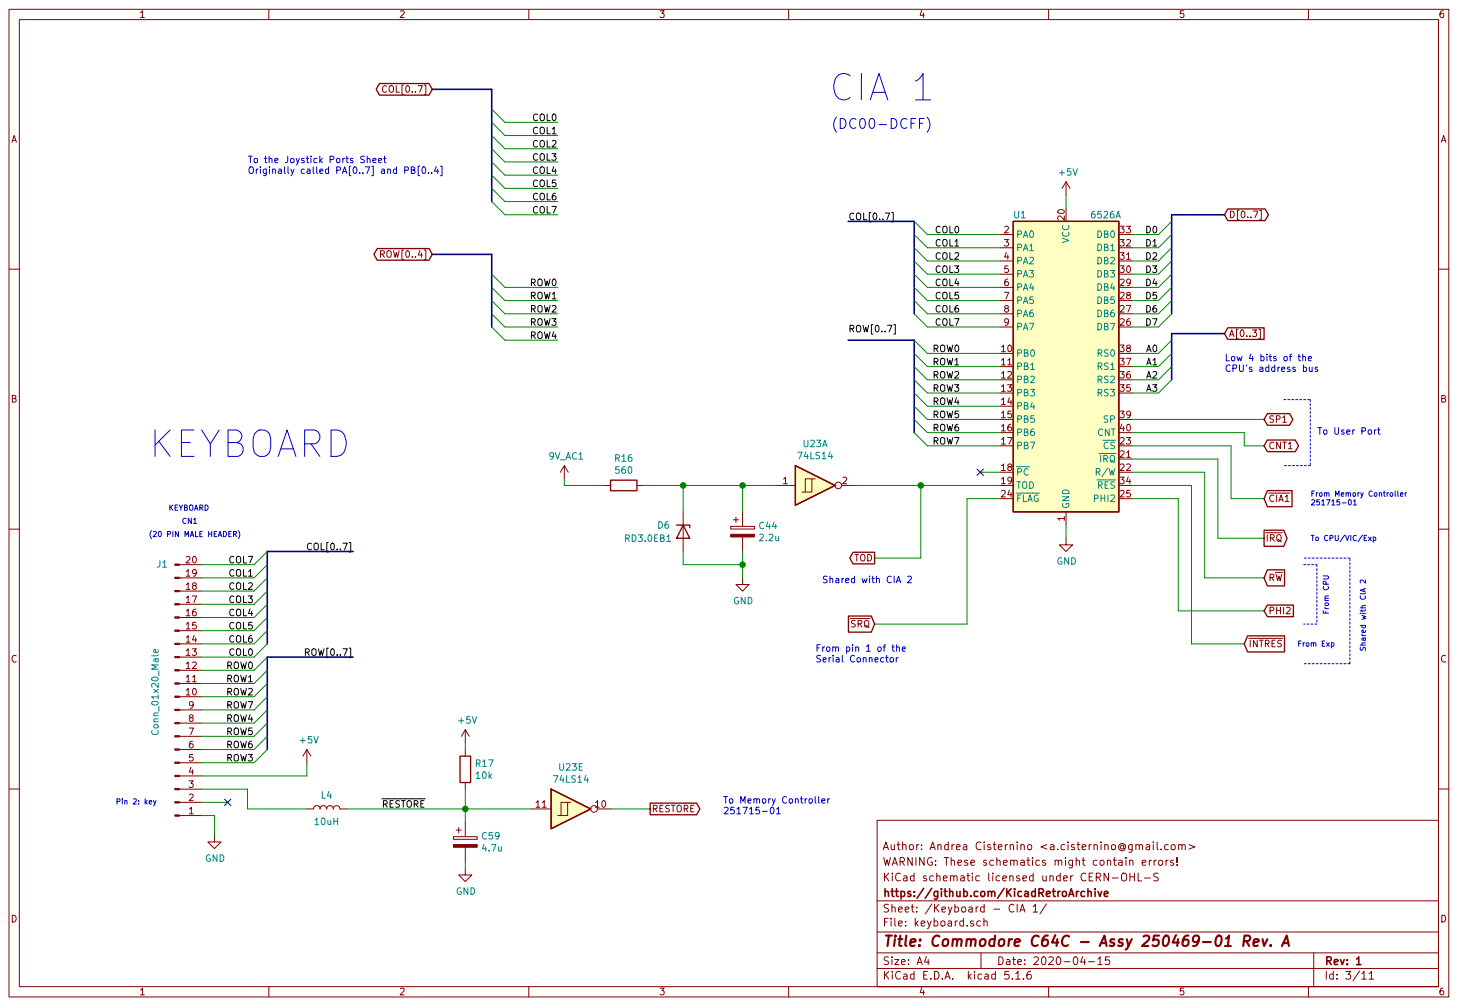
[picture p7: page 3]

To the Joystick Ports Sheet
Originally called PA[0..7] and PB[0..4]

Low 4 bits of the CPU's address bus

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

Sheet: /Keyboard - CIA 1/
File: keyboard.sch
Id: 3/11 Title: Commodore C64C - Assy 250469-01 Rev. A

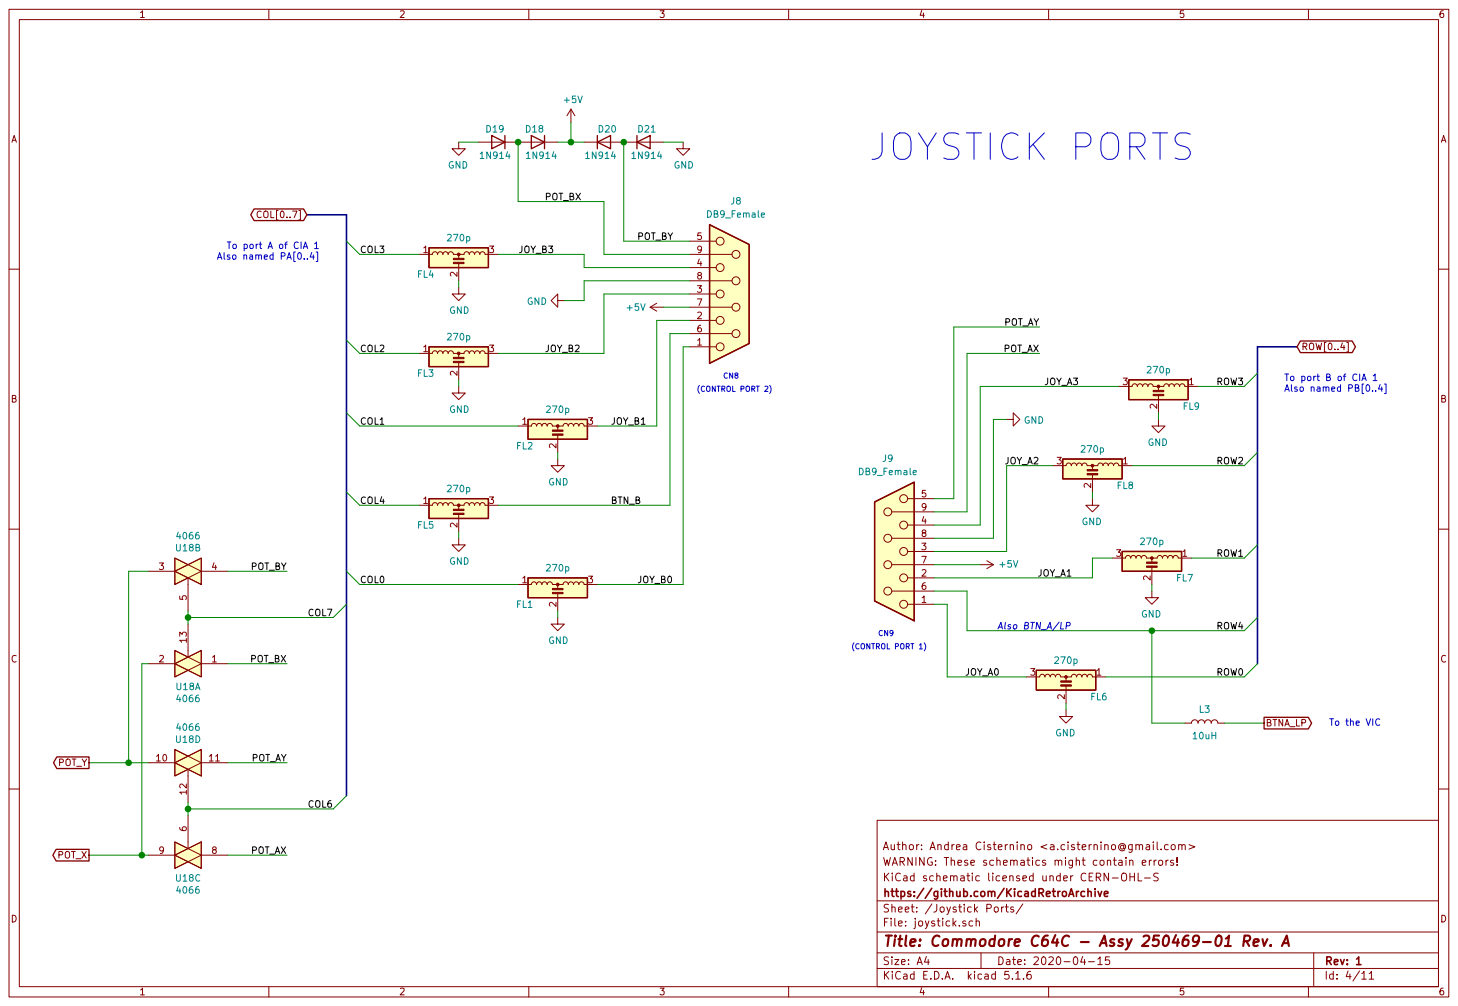
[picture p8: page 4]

To port A of CIA 1
Also named PA[0..4]

To port B of CIA 1

Also named PB[0..4] Also BTN_A/LP

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

Sheet: /Joystick Ports/
File: joystick.sch
Id: 4/11 Title: Commodore C64C - Assy 250469-01 Rev. A

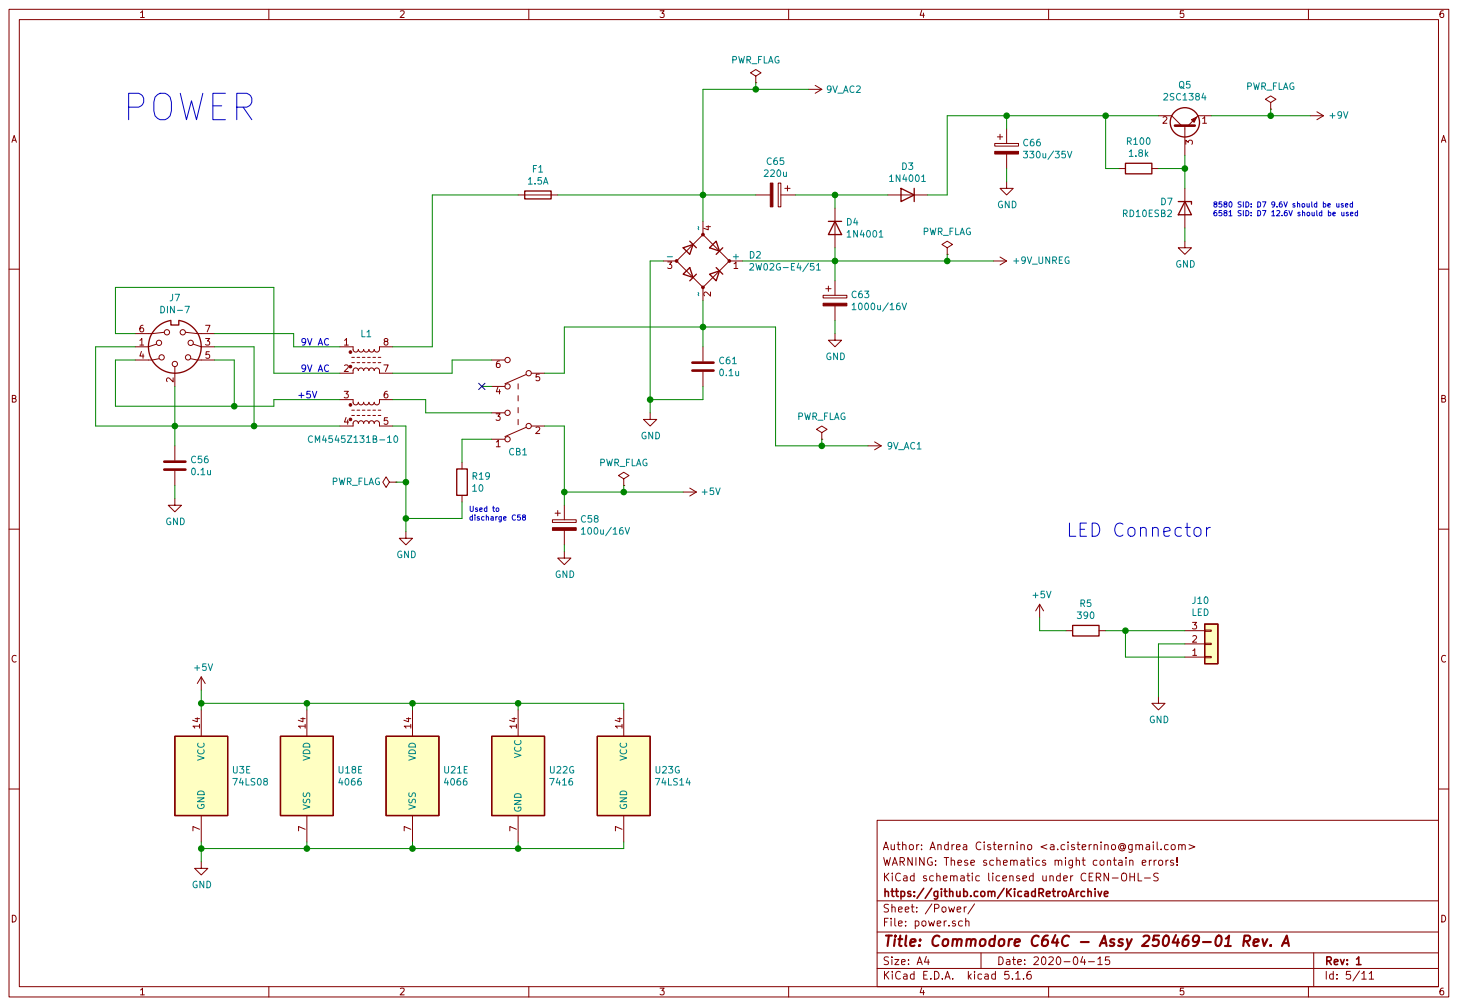
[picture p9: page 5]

8580 SID: D7 9.6V should be used
6581 SID: D7 12.6V should be used

Author: Andrea Cisternino <a.cisternino@gmail.com>
File: power.sch Sheet: /Power/ https://github.com/KicadRetroArchive KiCad schematic licensed under CERN-OHL-S WARNING: These schematics might contain errors!

Id: 5/11 Title: Commodore C64C - Assy 250469-01 Rev. A

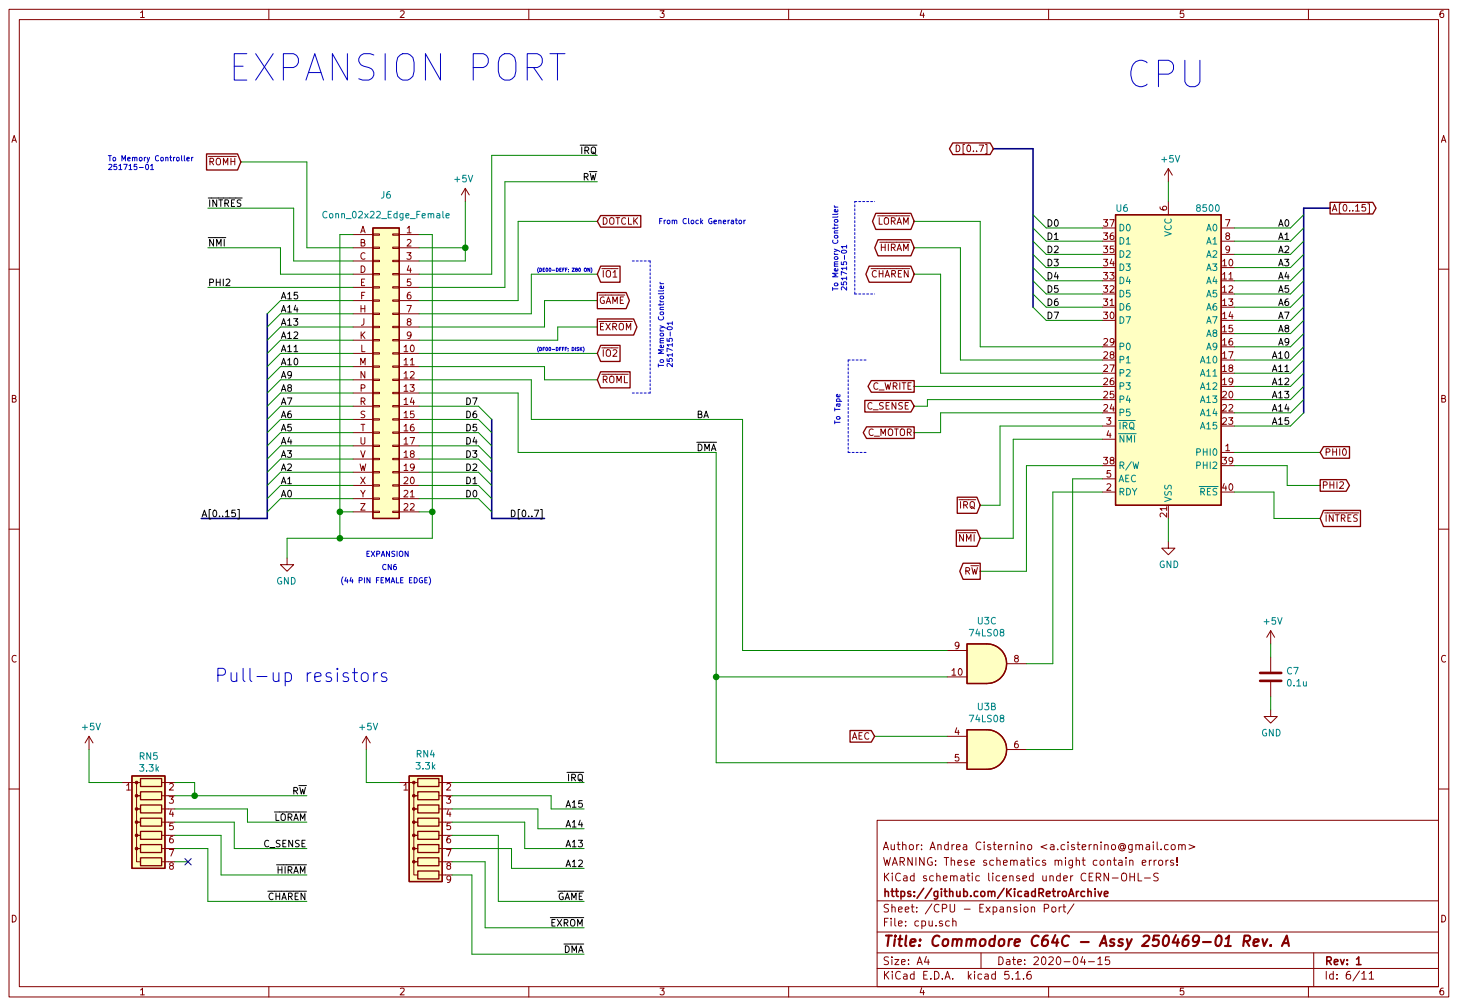
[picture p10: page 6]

FH | 6

N | 12
PR | 13

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

Sheet: /CPU - Expansion Port/
File: cpu.sch
Id: 6/11 Title: Commodore C64C - Assy 250469-01 Rev. A

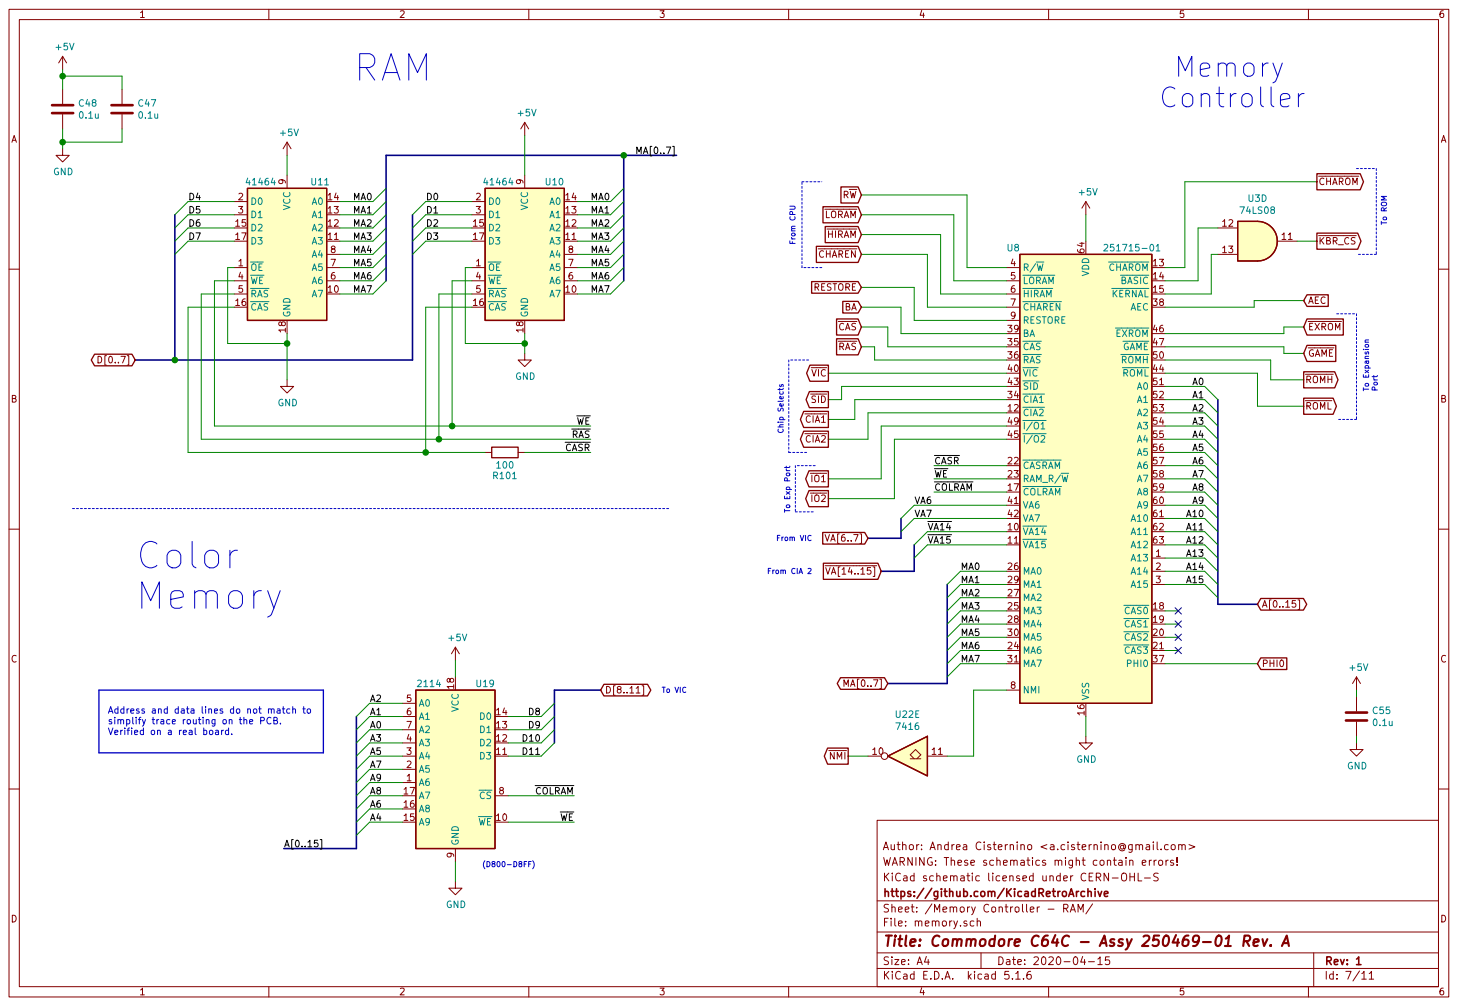
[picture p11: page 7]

From CIA 2 From VIC To Exp Port

Address and data lines do not match to

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

Sheet: /Memory Controller - RAM/
File: memory.sch
Id: 7/11 Title: Commodore C64C - Assy 250469-01 Rev. A

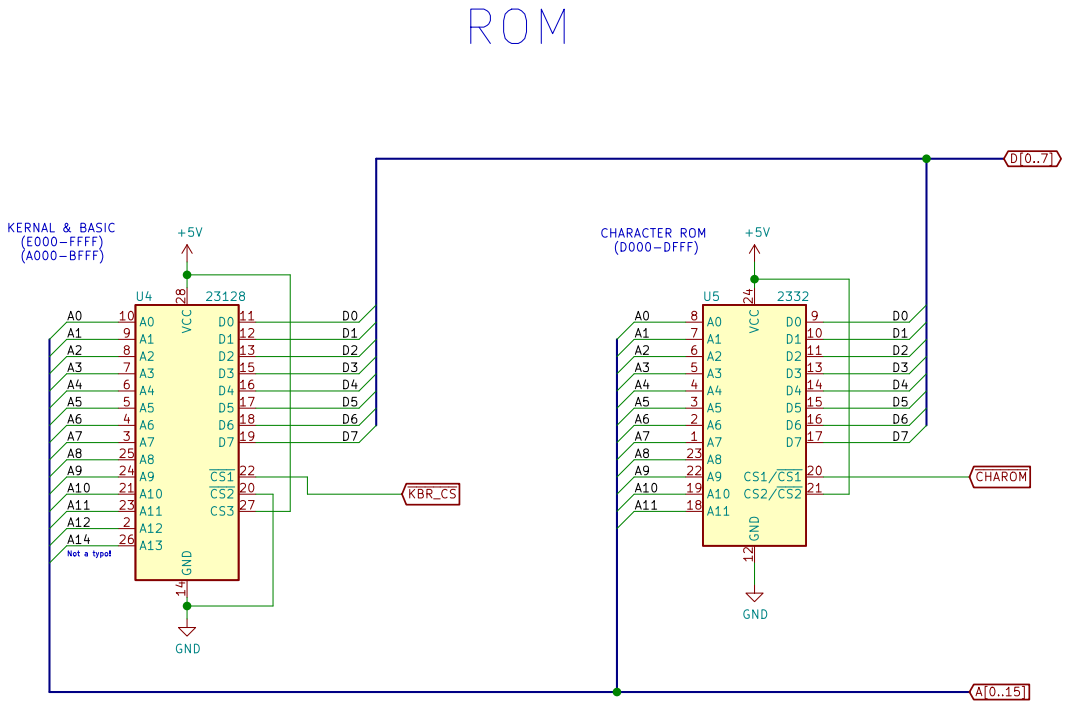
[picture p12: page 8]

Author: Andrea Cisternino <a.cisternino@gmail.com>
File: rom.sch Sheet: /ROM/ https://github.com/KicadRetroArchive KiCad schematic licensed under CERN-OHL-S WARNING: These schematics might contain errors!

Id: 8/11 Title: Commodore C64C - Assy 250469-01 Rev. A

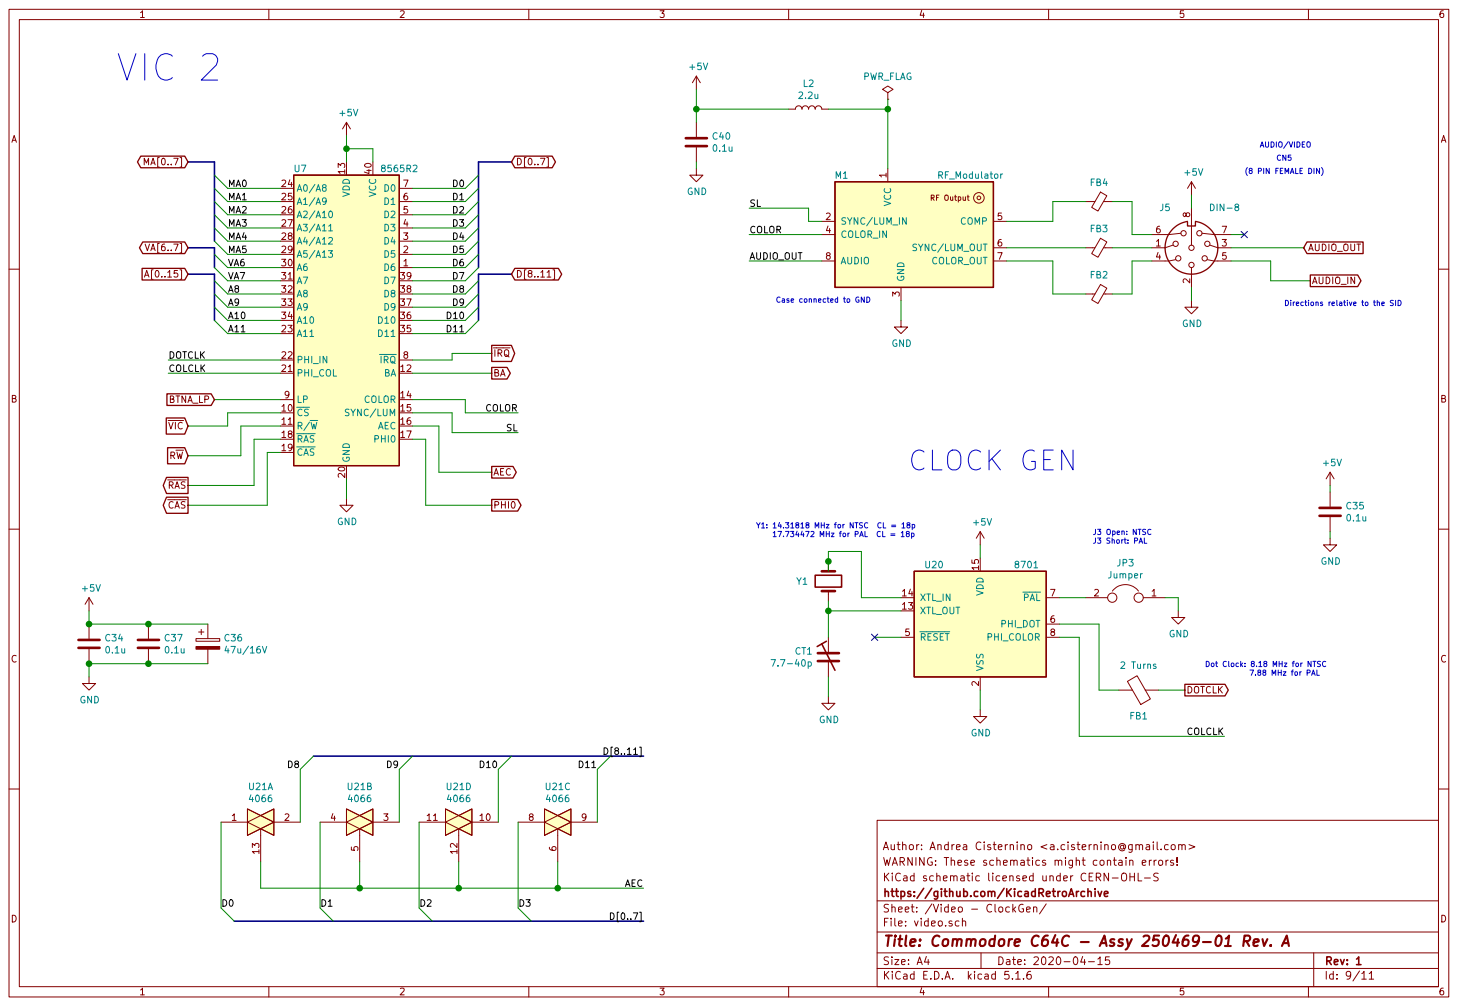
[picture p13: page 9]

(8 PIN FEMALE DIN) CN5 VIC 2

3 COLOR_IN 4 COMP 5 SYNC/LUM_OUT 6 COLOR_OUT 7 AUDIO 8 M1 RF_Modulator GND

Case connected to GND

Directions relative to the SID

Y1: 14.31818 MHz for NTSC CL = 18p

Author: Andrea Cisternino <a.cisternino@gmail.com>
File: video.sch Sheet: /Video - ClockGen/ https://github.com/KicadRetroArchive KiCad schematic licensed under CERN-OHL-S WARNING: These schematics might contain errors!

Id: 9/11 Title: Commodore C64C - Assy 250469-01 Rev. A

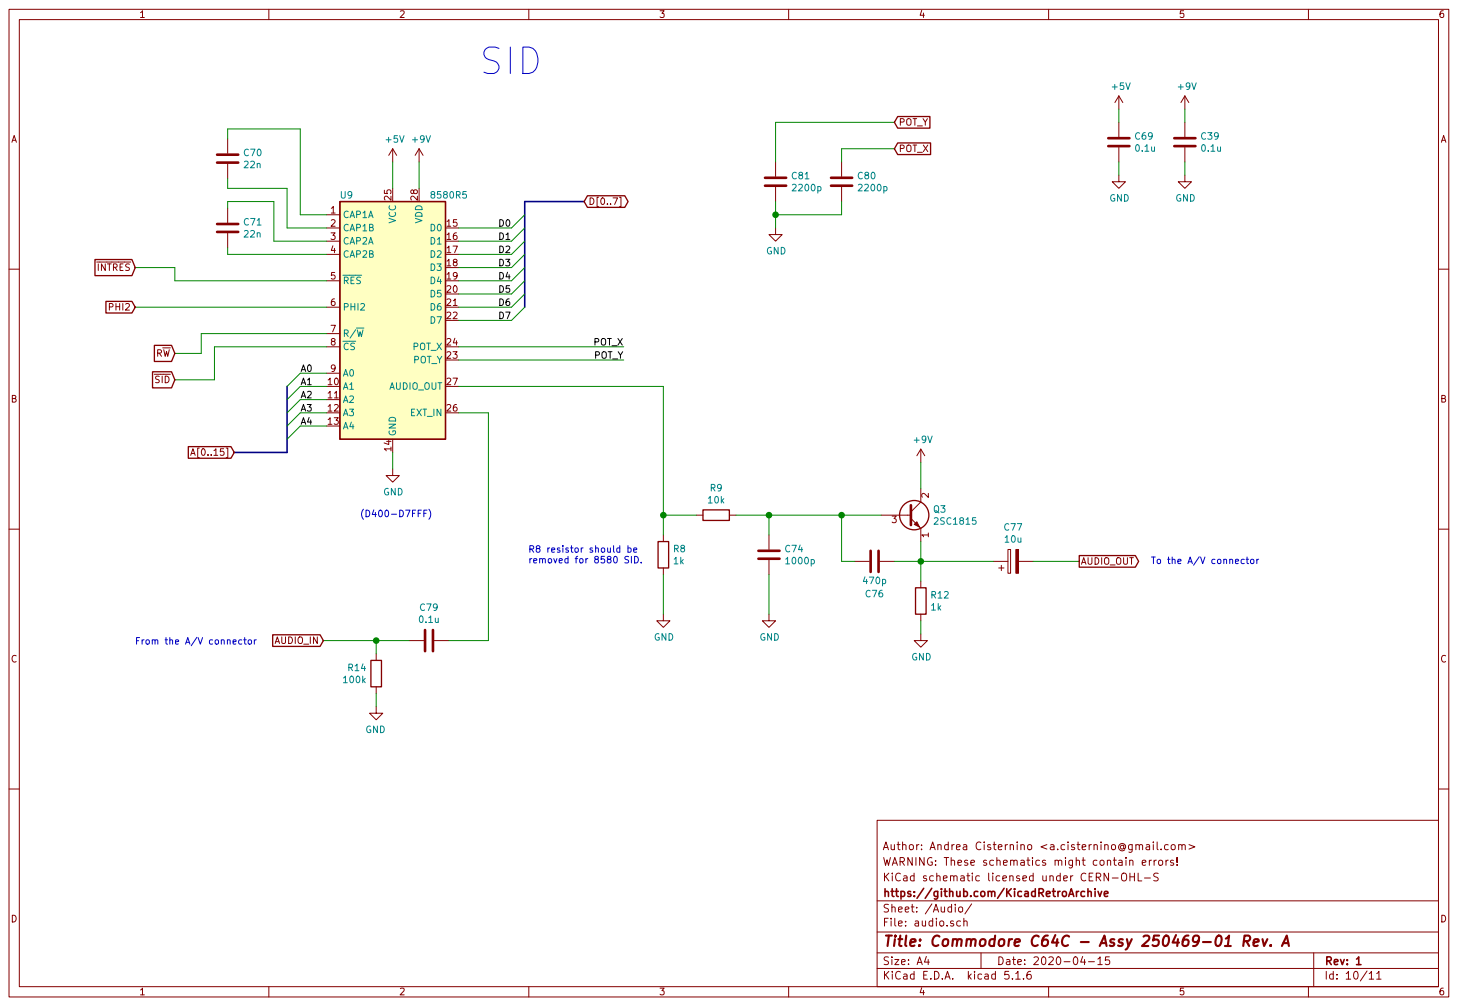
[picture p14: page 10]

Author: Andrea Cisternino <a.cisternino@gmail.com>
File: audio.sch Sheet: /Audio/ https://github.com/KicadRetroArchive KiCad schematic licensed under CERN-OHL-S WARNING: These schematics might contain errors!

Id: 10/11 Title: Commodore C64C - Assy 250469-01 Rev. A

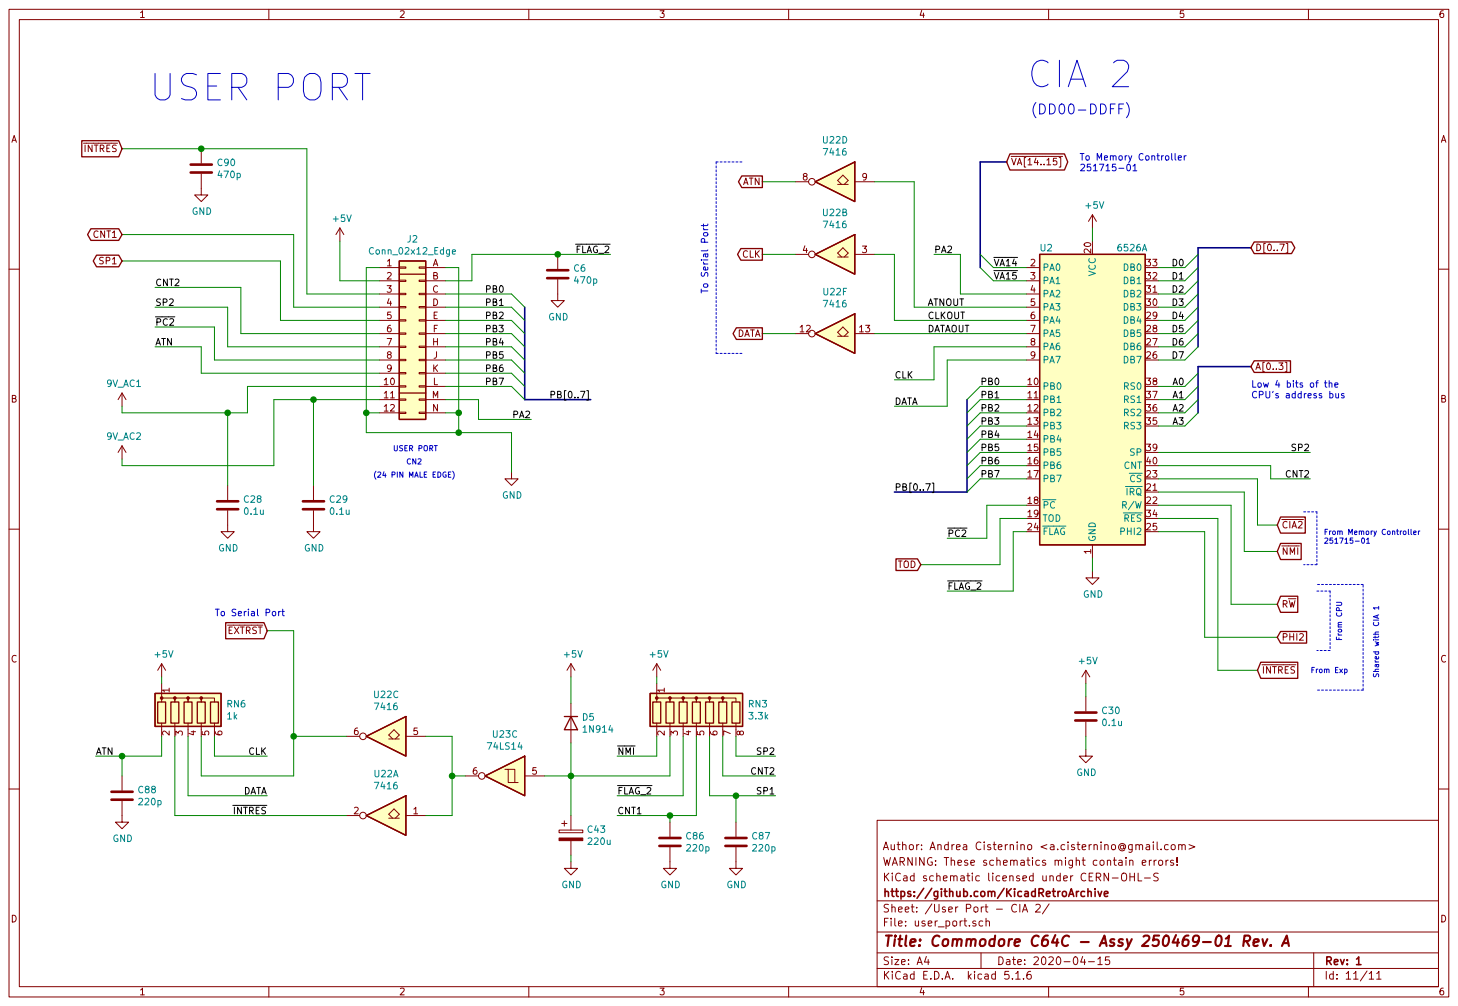
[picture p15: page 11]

From Exp USER PORT

6 | FH

10 | | LM
11
12 | N

Author: Andrea Cisternino <a.cisternino@gmail.com>
File: user_port.sch Sheet: /User Port - CIA 2/ https://github.com/KicadRetroArchive KiCad schematic licensed under CERN-OHL-S WARNING: These schematics might contain errors!

Id: 11/11 Title: Commodore C64C - Assy 250469-01 Rev. A

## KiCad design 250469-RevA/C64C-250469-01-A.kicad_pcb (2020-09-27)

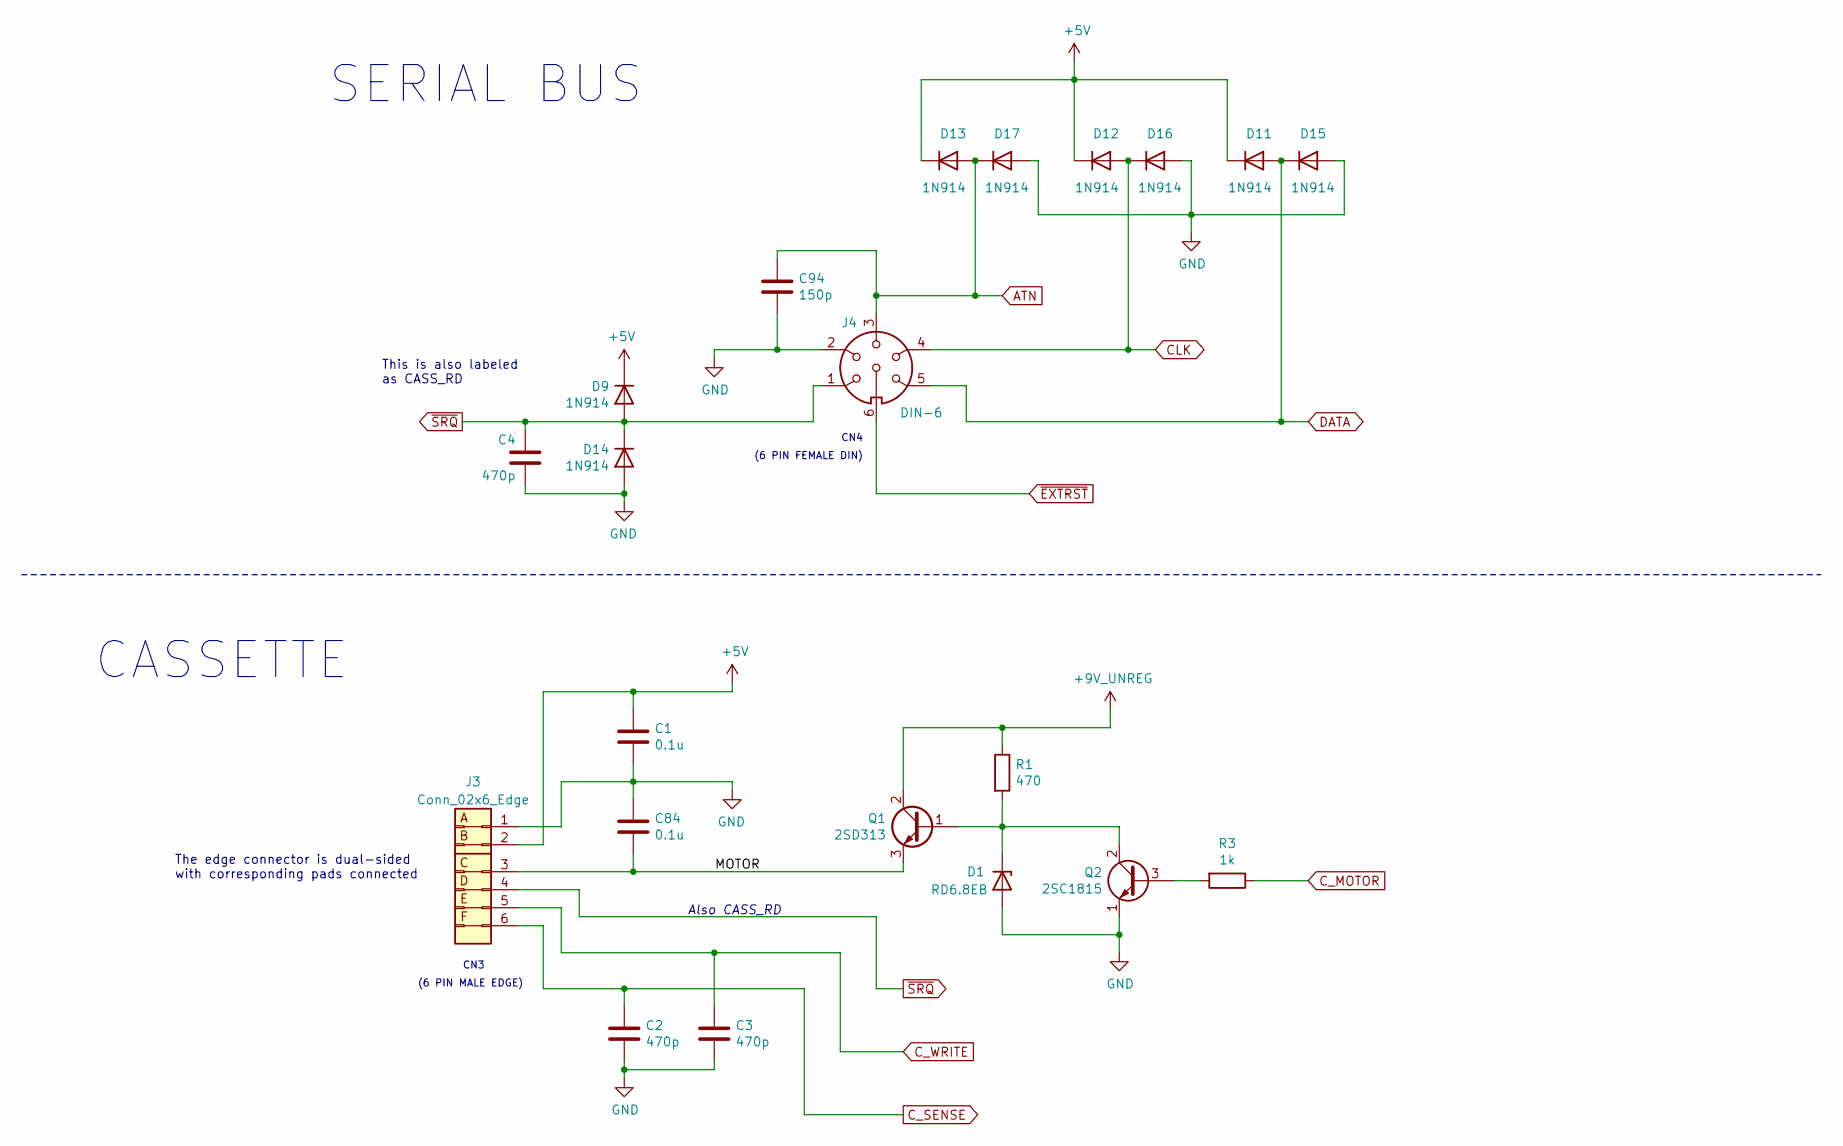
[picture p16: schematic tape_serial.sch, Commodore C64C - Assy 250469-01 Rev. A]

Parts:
C1, C84: 0.1u; C_Disc_D4.7mm_W2.5mm_P5.00mm
C2, C3, C4: 470p; C_Disc_D4.7mm_W2.5mm_P5.00mm
C94: 150p; C_Disc_D4.7mm_W2.5mm_P5.00mm
D1: RD6.8EB; D_DO-35_SOD27_P7.62mm_Horizontal
D9, D11, D12, D13, D14, D15, D16, D17: 1N914; D_DO-35_SOD27_P5.08mm_Vertical_KathodeUp
J3: Conn_02x6_Edge; Connector_Edge_2x6_P3.96mm
J4: DIN-6; C64_Original_DIN-6_Circular
Q1: 2SD313; TO-220-3_Horizontal_TabDown
Q2: 2SC1815; TO-92_Inline
R1: 470; R_Axial_DIN0309_L9.0mm_D3.2mm_P15.24mm_Horizontal
R3: 1k; R_Axial_DIN0207_L6.3mm_D2.5mm_P5.08mm_Vertical

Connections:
+5V: C1.1, D9.1 (K), D11.1 (K), D12.1 (K), D13.1 (K), J3.2, J3.B; also elsewhere on the board
+9V_UNREG: Q1.2 (C), R1.1; also elsewhere on the board
/Tape - Serial/MOTOR: C84.2, J3.3, Q1.3 (E)
ATN: C94.1, D13.2 (A), D17.1 (K), J4.3; also elsewhere on the board
CLK: D12.2 (A), D16.1 (K), J4.4; also elsewhere on the board
C_MOTOR: R3.1; also elsewhere on the board
C_SENSE: C2.1, J3.6; also elsewhere on the board
C_WRITE: C3.1, J3.5; also elsewhere on the board
DATA: D11.2 (A), D15.1 (K), J4.5; also elsewhere on the board
GND: C1.2, C2.2, C3.2, C4.2, C84.1, C94.2, D1.2 (A), D14.2 (A), D15.2 (A), D16.2 (A), D17.2 (A), J3.1, J4.0, J4.2, Q2.1 (E); also elsewhere on the board
unnamed: D1.1 (K), Q1.1 (B), Q2.2 (C), R1.2
unnamed: Q2.3 (B), R3.2
~EXTRST: J4.6; also elsewhere on the board
~SRQ: C4.1, D9.2 (A), D14.1 (K), J3.4, J3.D, J4.1; also elsewhere on the board

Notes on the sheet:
CN4
SERIAL BUS
CN3
CASSETTE
Also CASS_RD
(6 PIN MALE EDGE)
(6 PIN FEMALE DIN)
This is also labeled as CASS_RD
The edge connector is dual-sided with corresponding pads connected

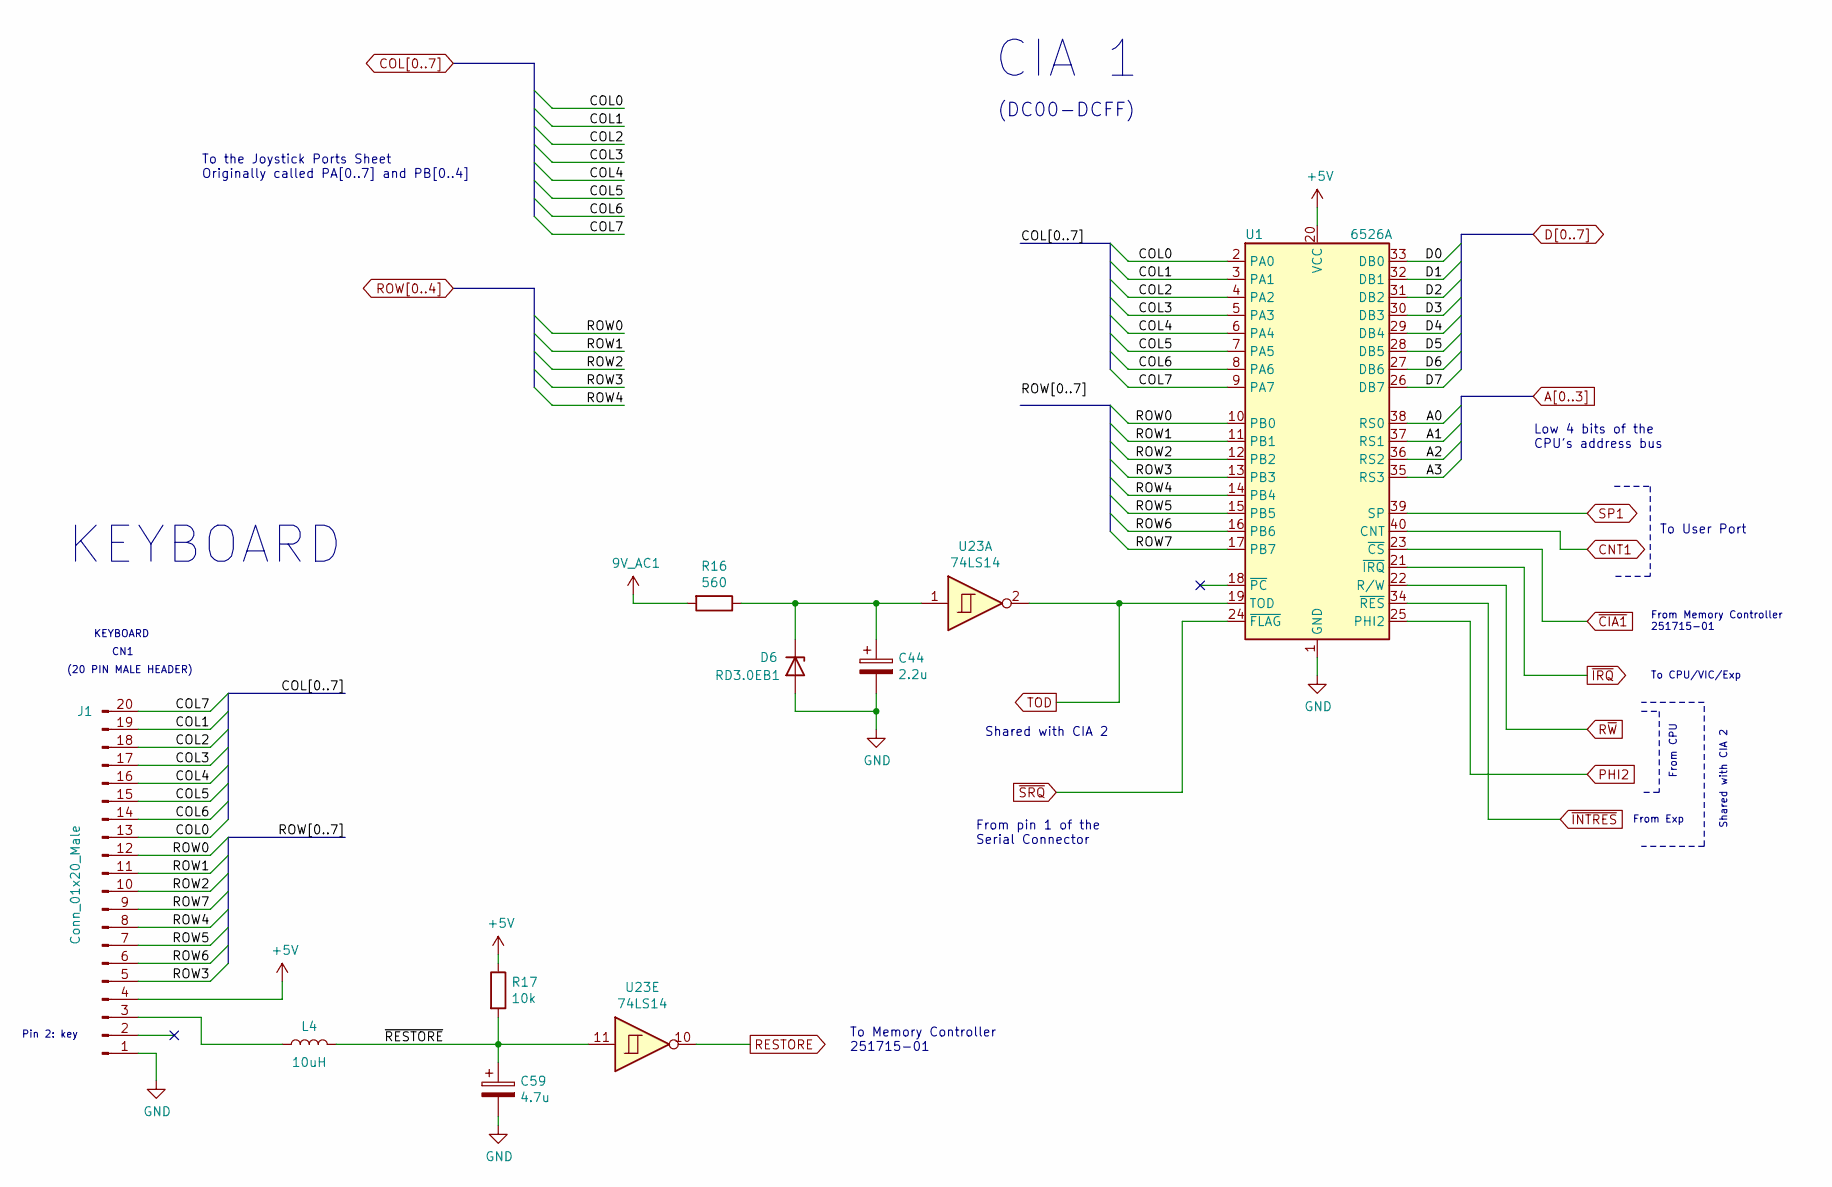
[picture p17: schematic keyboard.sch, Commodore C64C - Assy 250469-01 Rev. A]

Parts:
C44: 2.2u; CP_Radial_D8.0mm_P5.00mm
C59: 4.7u; CP_Radial_D8.0mm_P5.00mm
D6: RD3.0EB1; D_DO-35_SOD27_P5.08mm_Vertical_KathodeUp
J1: Conn_01x20_Male; PinHeader_1x20_P2.54mm_Vertical
L4: 10uH; L_Radial_L7.5mm_W3mm_P5.00mm_Kemet_SBT-02
R16: 560; R_Axial_DIN0207_L6.3mm_D2.5mm_P5.08mm_Vertical
R17: 10k; R_Axial_DIN0207_L6.3mm_D2.5mm_P5.08mm_Vertical
U1: 6526A; DIP-40_W15.24mm_Socket
U23: 74LS14; DIP-14_W7.62mm_Socket

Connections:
9V_AC1: R16.2; also elsewhere on the board
+5V: J1.4, R17.1, U1.20 (VCC); also elsewhere on the board
/Keyboard - CIA 1/ROW5: J1.7, U1.15 (PB5)
/Keyboard - CIA 1/ROW6: J1.6, U1.16 (PB6)
/Keyboard - CIA 1/ROW7: J1.9, U1.17 (PB7)
/Keyboard - CIA 1/~RESTORE: C59.1, L4.2, R17.2, U23.11
A0: U1.38 (RS0); also elsewhere on the board
A1: U1.37 (RS1); also elsewhere on the board
A2: U1.36 (RS2); also elsewhere on the board
A3: U1.35 (RS3); also elsewhere on the board
CNT1: U1.40 (CNT); also elsewhere on the board
COL0: J1.13, U1.2 (PA0); also elsewhere on the board
COL1: J1.19, U1.3 (PA1); also elsewhere on the board
COL2: J1.18, U1.4 (PA2); also elsewhere on the board
COL3: J1.17, U1.5 (PA3); also elsewhere on the board
COL4: J1.16, U1.6 (PA4); also elsewhere on the board
COL5: J1.15, U1.7 (PA5)
COL6: J1.14, U1.8 (PA6); also elsewhere on the board
COL7: J1.20, U1.9 (PA7); also elsewhere on the board
D0: U1.33 (DB0); also elsewhere on the board
D1: U1.32 (DB1); also elsewhere on the board
D2: U1.31 (DB2); also elsewhere on the board
D3: U1.30 (DB3); also elsewhere on the board
D4: U1.29 (DB4); also elsewhere on the board
D5: U1.28 (DB5); also elsewhere on the board
D6: U1.27 (DB6); also elsewhere on the board
D7: U1.26 (DB7); also elsewhere on the board
GND: C44.2, C59.2, D6.2 (A), J1.1, U1.1 (GND); also elsewhere on the board
unnamed: C44.1, D6.1 (K), R16.1, U23.1
unnamed: J1.3, L4.1
PHI2: U1.25 (PHI2); also elsewhere on the board
RESTORE: U23.10; also elsewhere on the board
ROW0: J1.12, U1.10 (PB0); also elsewhere on the board
ROW1: J1.11, U1.11 (PB1); also elsewhere on the board
ROW2: J1.10, U1.12 (PB2); also elsewhere on the board
ROW3: J1.5, U1.13 (PB3); also elsewhere on the board
ROW4: J1.8, U1.14 (PB4); also elsewhere on the board
R~W: U1.22 (R/W); also elsewhere on the board
SP1: U1.39 (SP); also elsewhere on the board
TOD: U1.19 (TOD), U23.2; also elsewhere on the board
~CIA1: U1.23 (~CS); also elsewhere on the board
~INTRES: U1.34 (~RES); also elsewhere on the board
~IRQ: U1.21 (~IRQ); also elsewhere on the board
~SRQ: U1.24 (~FLAG); also elsewhere on the board

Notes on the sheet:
KEYBOARD
CN1
(20 PIN MALE HEADER)
(DC00-DCFF)
Pin 2: key
Low 4 bits of the CPU's address bus
CIA 1
From pin 1 of the Serial Connector
To the Joystick Ports Sheet Originally called PA[0..7] and PB[0..4]
Shared with CIA 2
To User Port
From Memory Controller 251715-01
To Memory Controller 251715-01
To CPU/VIC/Exp
From CPU
From Exp

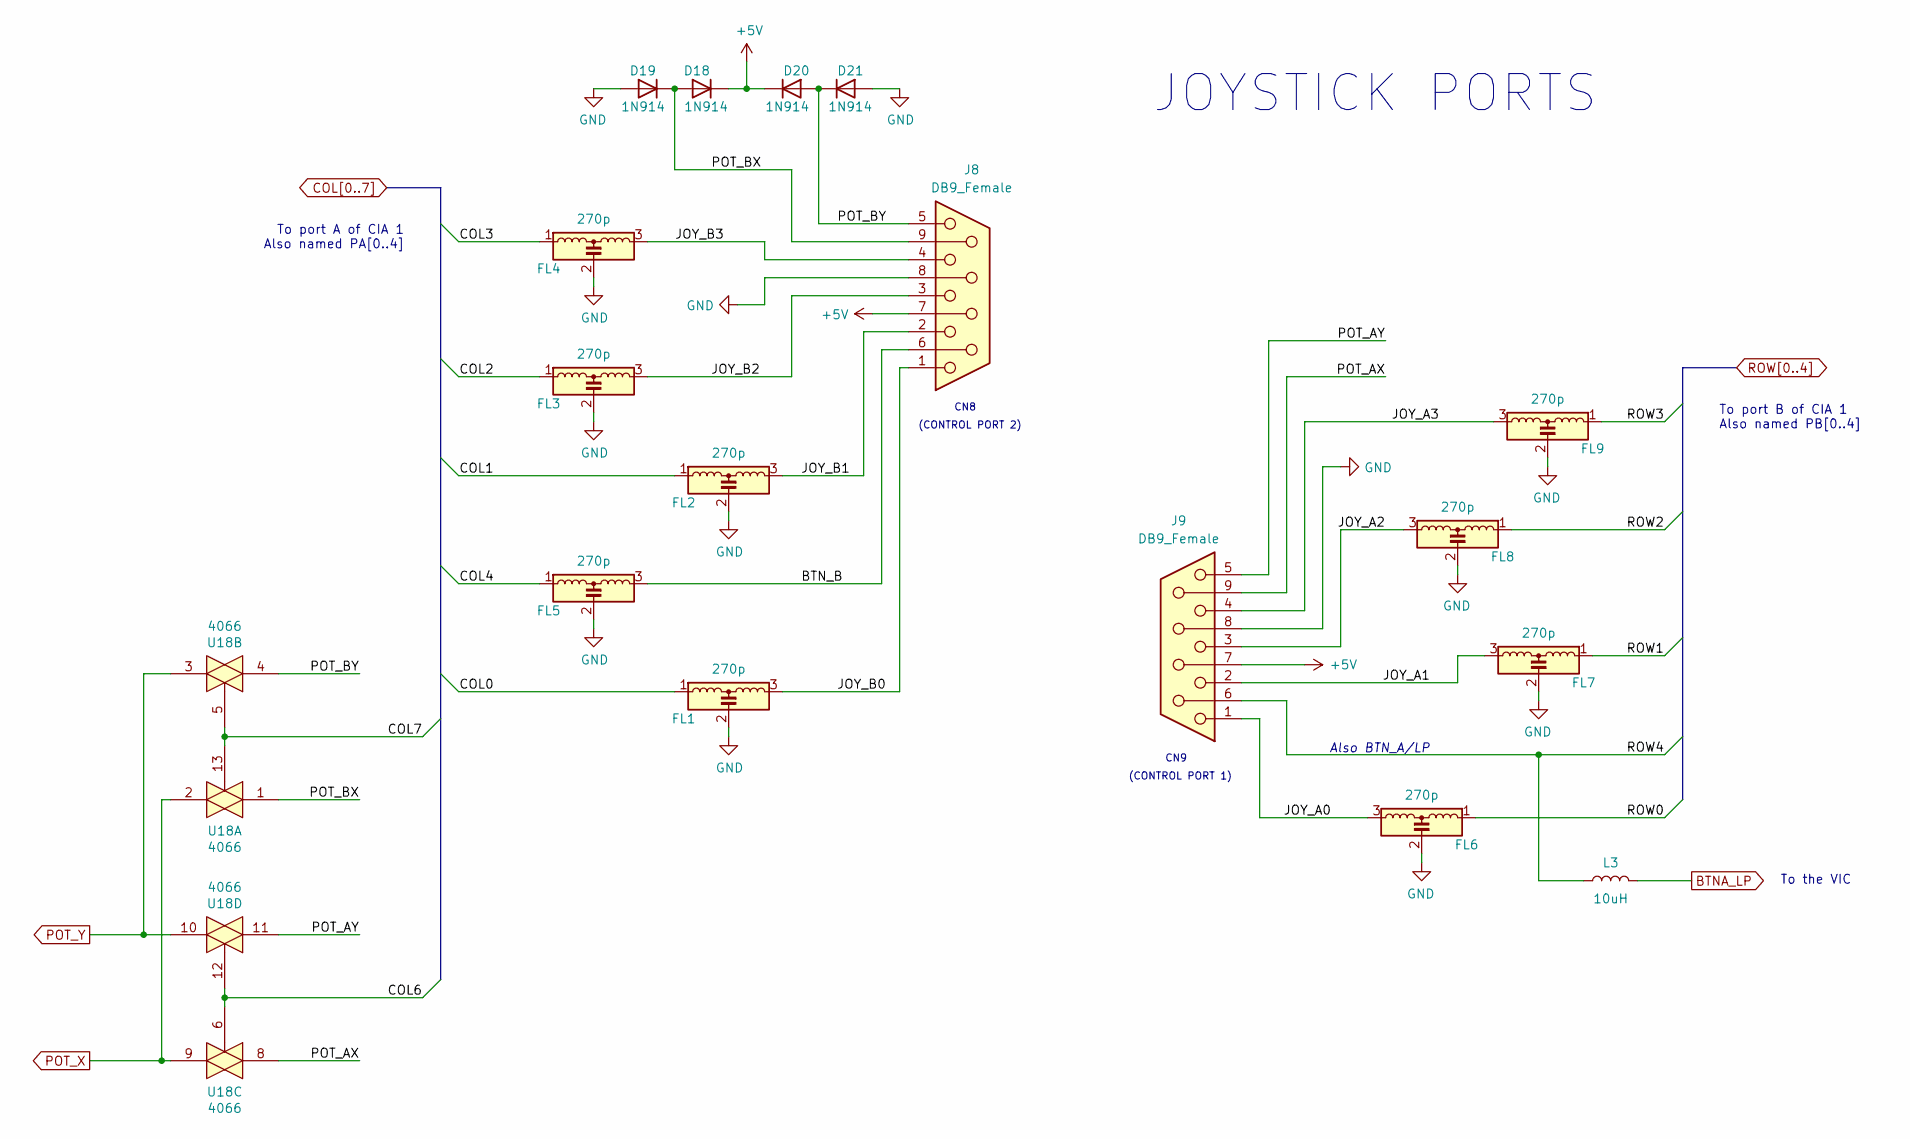
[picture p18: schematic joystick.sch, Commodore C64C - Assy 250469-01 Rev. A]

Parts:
D18, D19, D20, D21: 1N914; D_DO-35_SOD27_P5.08mm_Vertical_KathodeUp
FL1, FL2, FL3, FL4, FL5, FL6, FL7, FL8, FL9: 270p; LCL-Filter_2.8x8.5mm_P2.5mm
J8, J9: DB9_Female; Kycon_K22X-E9P-N_DSUB-9_Male_Horizontal
L3: 10uH; L_Radial_L7.5mm_W3mm_P5.00mm_Kemet_SBT-02
U18: 4066; DIP-14_W7.62mm_Socket

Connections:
+5V: D18.1 (K), D20.1 (K), J8.7, J9.7; also elsewhere on the board
/Joystick Ports/BTN_B: FL5.3, J8.6
/Joystick Ports/JOY_A0: FL6.3, J9.1
/Joystick Ports/JOY_A1: FL7.3, J9.2
/Joystick Ports/JOY_A2: FL8.3, J9.3
/Joystick Ports/JOY_A3: FL9.3, J9.4
/Joystick Ports/JOY_B0: FL1.3, J8.1
/Joystick Ports/JOY_B1: FL2.3, J8.2
/Joystick Ports/JOY_B2: FL3.3, J8.3
/Joystick Ports/JOY_B3: FL4.3, J8.4
/Joystick Ports/POT_AX: J9.9, U18.8
/Joystick Ports/POT_AY: J9.5, U18.11
/Joystick Ports/POT_BX: D18.2 (A), D19.1 (K), J8.9, U18.1
/Joystick Ports/POT_BY: D20.2 (A), D21.1 (K), J8.5, U18.4
BTNA_LP: L3.1; also elsewhere on the board
COL0: FL1.1; also elsewhere on the board
COL1: FL2.1; also elsewhere on the board
COL2: FL3.1; also elsewhere on the board
COL3: FL4.1; also elsewhere on the board
COL4: FL5.1; also elsewhere on the board
COL6: U18.6, U18.12; also elsewhere on the board
COL7: U18.5, U18.13; also elsewhere on the board
GND: D19.2 (A), D21.2 (A), FL1.2, FL2.2, FL3.2, FL4.2, FL5.2, FL6.2, FL7.2, FL8.2, FL9.2, J8.8, J9.8; also elsewhere on the board
POT_X: U18.2, U18.9; also elsewhere on the board
POT_Y: U18.3, U18.10; also elsewhere on the board
ROW0: FL6.1; also elsewhere on the board
ROW1: FL7.1; also elsewhere on the board
ROW2: FL8.1; also elsewhere on the board
ROW3: FL9.1; also elsewhere on the board
ROW4: J9.6, L3.2; also elsewhere on the board

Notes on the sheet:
CN8
(CONTROL PORT 2)
CN9
(CONTROL PORT 1)
Also BTN_A/LP
JOYSTICK PORTS
To the VIC
To port B of CIA 1 Also named PB[0..4]
To port A of CIA 1 Also named PA[0..4]

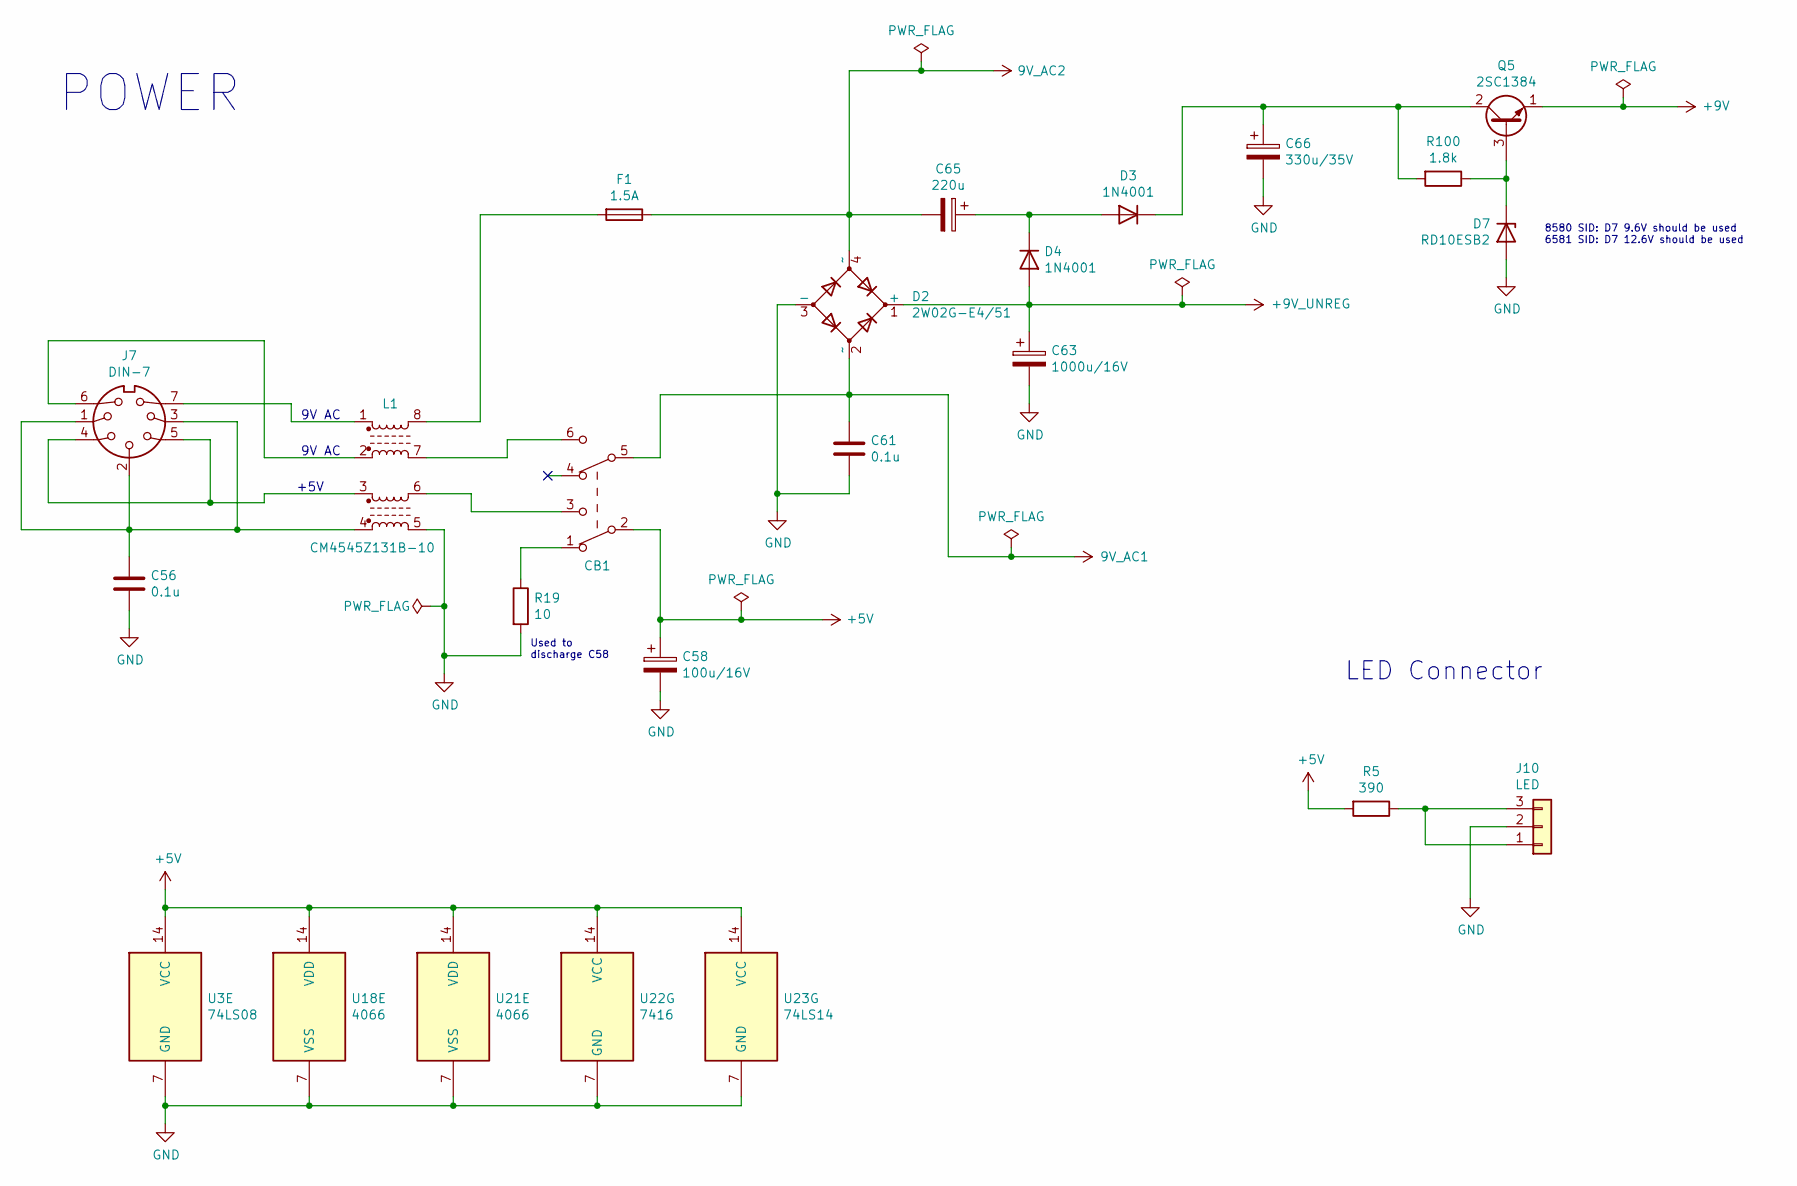
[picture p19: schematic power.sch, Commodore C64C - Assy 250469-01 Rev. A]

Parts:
C56, C61: 0.1u; C_Disc_D4.7mm_W2.5mm_P5.00mm
C58: 100u/16V; CP_Radial_D10.0mm_P5.00mm
C63: 1000u/16V; CP_Axial_L30.0mm_D15.0mm_P35.00mm_Horizontal
C65: 220u; CP_Radial_D10.0mm_P5.00mm
C66: 330u/35V; CP_Radial_D12.5mm_P5.00mm
CB1: SW_DPDT; RockerSwitch_CuK_DPDT_E201J1AV2
D2: 2W02G-E4/51; Diode_Bridge_Round_D9.8mm
D3, D4: 1N4001; D_DO-41_SOD81_P5.08mm_Vertical_KathodeUp
D7: RD10ESB2; D_DO-34_SOD68_P5.08mm_Vertical_KathodeUp
F1: 1.5A; Fuseclip_Cylinder-6.3x32mm
J7: DIN-7; C64_Original_DIN-7_Circular
J10: LED; PinHeader_1x03_P2.54mm_Vertical
L1: CM4545Z131B-10; Laird_CM4545Z131B-10
Q5: 2SC1384; TO-92_Inline_Wide
R5: 390; R_Axial_DIN0207_L6.3mm_D2.5mm_P5.08mm_Vertical
R19: 10; R_Axial_DIN0309_L9.0mm_D3.2mm_P15.24mm_Horizontal
R100: 1.8k; R_Axial_DIN0207_L6.3mm_D2.5mm_P5.08mm_Vertical
U3: 74LS08; DIP-14_W7.62mm_Socket
U18, U21: 4066; DIP-14_W7.62mm_Socket
U22: 7416; DIP-14_W7.62mm_Socket
U23: 74LS14; DIP-14_W7.62mm_Socket

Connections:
9V_AC1: C61.1, CB1.5 (B), D2.2 (~~); also elsewhere on the board
9V_AC2: C65.2, D2.4 (~~), F1.1; also elsewhere on the board
+5V: C58.1, CB1.2 (B), R5.2, U3.14 (VCC), U18.14 (VDD), U21.14 (VDD), U22.14 (VCC), U23.14 (VCC); also elsewhere on the board
+9V: Q5.1 (E); also elsewhere on the board
+9V_UNREG: C63.1, D2.1 (+), D4.2 (A); also elsewhere on the board
GND: C56.2, C58.2, C61.2, C63.2, C66.2, D2.3 (-), D7.2 (A), J7.0, J10.2, L1.5, R19.2, U3.7 (GND), U18.7 (VSS), U21.7 (VSS), U22.7 (GND), U23.7 (GND); also elsewhere on the board
unnamed: C56.1, J7.1, J7.2, J7.3, L1.4
unnamed: C65.1, D3.2 (A), D4.1 (K)
unnamed: C66.1, D3.1 (K), Q5.2 (C), R100.2
unnamed: CB1.1 (A), R19.1
unnamed: CB1.3 (C), L1.6
unnamed: CB1.6 (C), L1.7
unnamed: D7.1 (K), Q5.3 (B), R100.1
unnamed: F1.2, L1.8
unnamed: J7.4, J7.5, L1.3
unnamed: J7.6, L1.2
unnamed: J7.7, L1.1
unnamed: J10.1, J10.3, R5.1

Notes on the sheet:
+5V
9V AC
8580 SID: D7 9.6V should be used 6581 SID: D7 12.6V should be used
POWER
LED Connector
Used to discharge C58

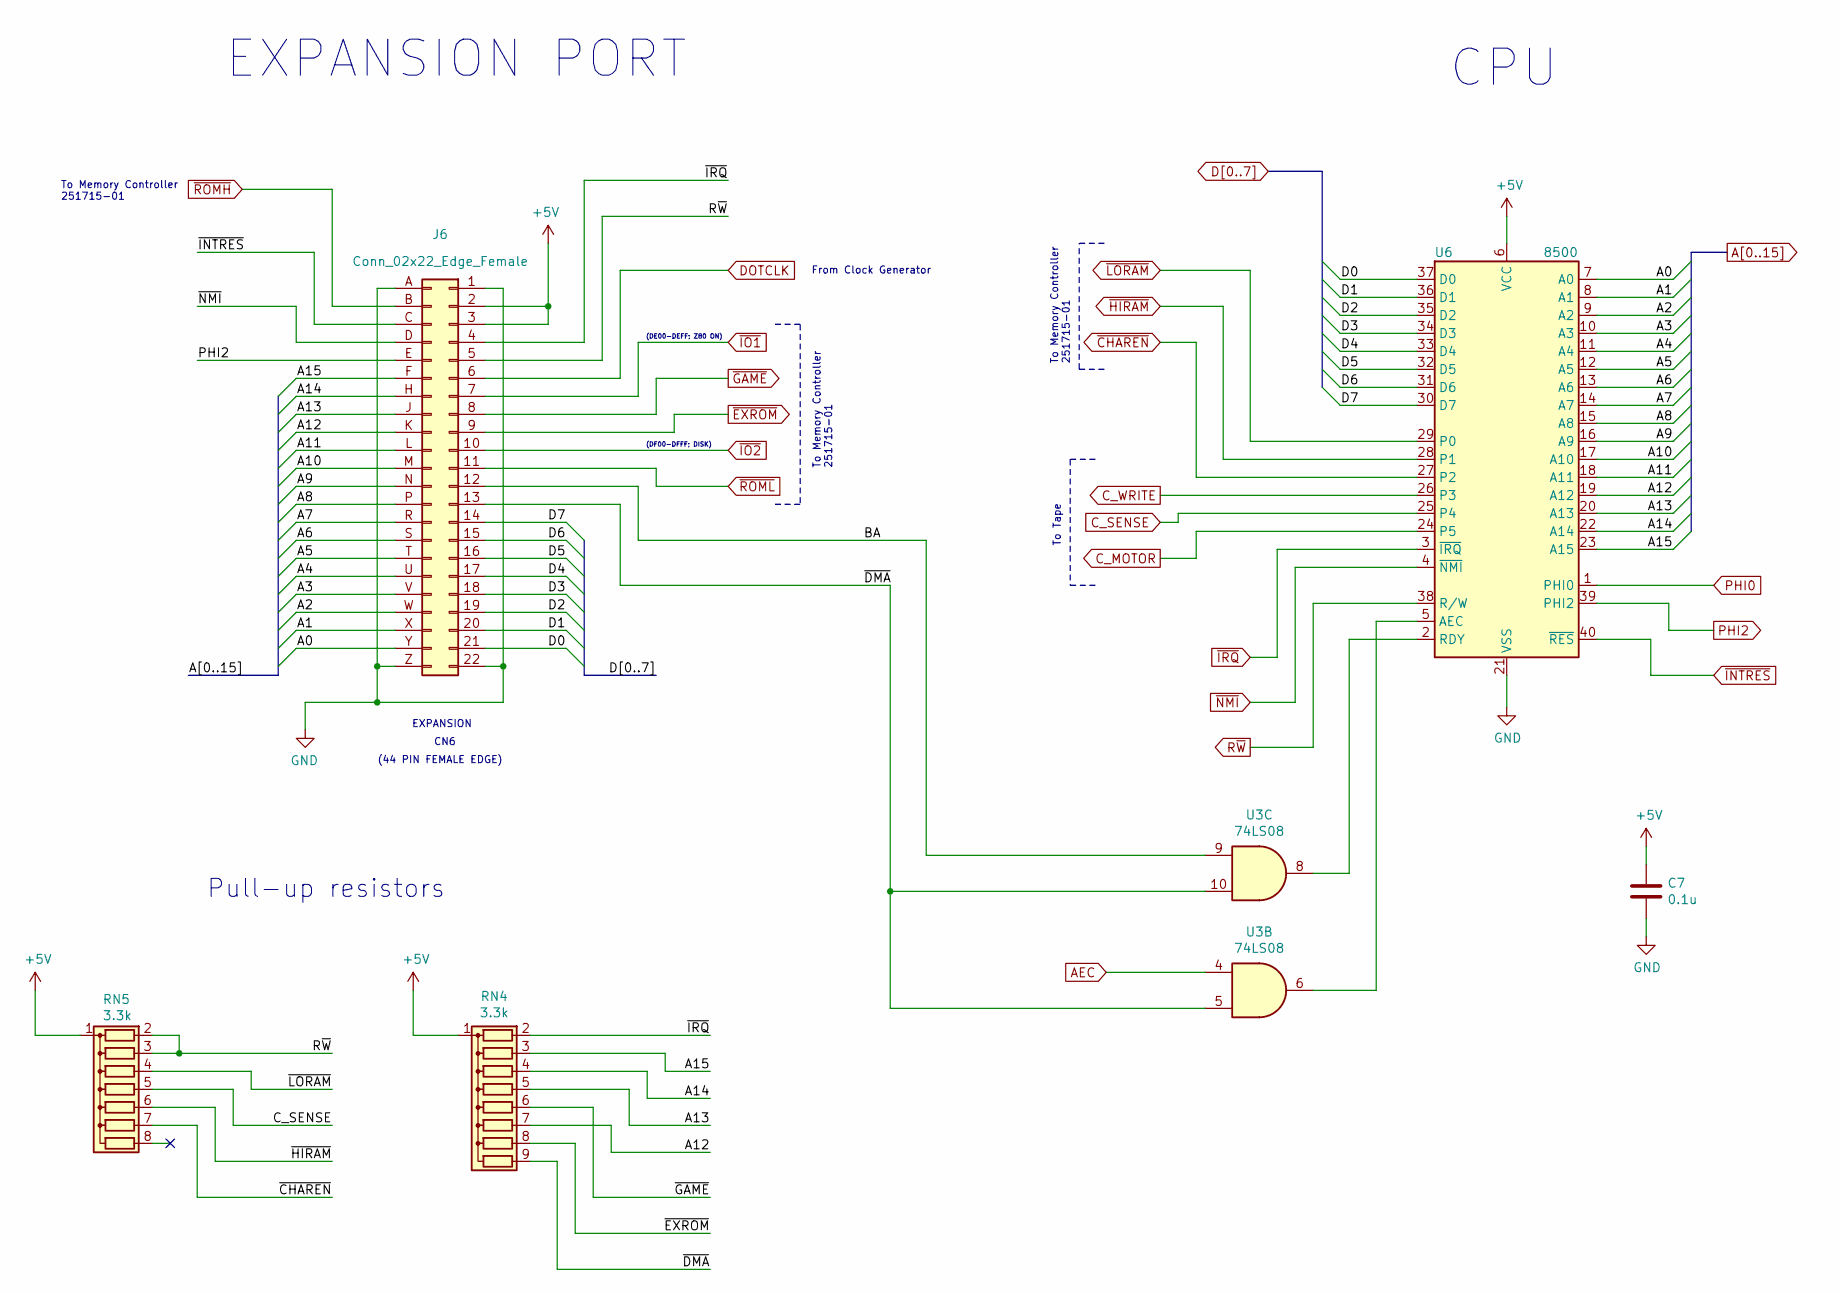
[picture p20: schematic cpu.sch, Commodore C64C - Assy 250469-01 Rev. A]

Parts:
C7: 0.1u; C_Disc_D4.7mm_W2.5mm_P5.00mm
J6: Conn_02x22_Edge_Female; Sullins_EBC22DRAN
RN4: 3.3k; R_Array_SIP9
RN5: 3.3k; R_Array_SIP8
U3: 74LS08; DIP-14_W7.62mm_Socket
U6: 8500; DIP-40_W15.24mm_Socket

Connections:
+5V: C7.1, J6.2, J6.3, RN4.1 (common), RN5.1 (common), U6.6 (VCC); also elsewhere on the board
/CPU - Expansion Port/BA: J6.12, U3.9
/CPU - Expansion Port/~DMA: J6.13, RN4.9 (R8), U3.5, U3.10
A0: J6.Y, U6.7 (A0); also elsewhere on the board
A1: J6.X, U6.8 (A1); also elsewhere on the board
A2: J6.W, U6.9 (A2); also elsewhere on the board
A3: J6.V, U6.10 (A3); also elsewhere on the board
A4: J6.U, U6.11 (A4); also elsewhere on the board
A5: J6.T, U6.12 (A5); also elsewhere on the board
A6: J6.S, U6.13 (A6); also elsewhere on the board
A7: J6.R, U6.14 (A7); also elsewhere on the board
A8: J6.P, U6.15 (A8); also elsewhere on the board
A9: J6.N, U6.16 (A9); also elsewhere on the board
A10: J6.M, U6.17 (A10); also elsewhere on the board
A11: J6.L, U6.18 (A11); also elsewhere on the board
A12: J6.K, RN4.7 (R6), U6.19 (A12); also elsewhere on the board
A13: J6.J, RN4.5 (R4), U6.20 (A13); also elsewhere on the board
A14: J6.H, RN4.4 (R3), U6.22 (A14); also elsewhere on the board
A15: J6.F, RN4.3 (R2), U6.23 (A15); also elsewhere on the board
AEC: U3.4; also elsewhere on the board
C_MOTOR: U6.24 (P5); also elsewhere on the board
C_SENSE: RN5.5 (R4), U6.25 (P4); also elsewhere on the board
C_WRITE: U6.26 (P3); also elsewhere on the board
D0: J6.21, U6.37 (D0); also elsewhere on the board
D1: J6.20, U6.36 (D1); also elsewhere on the board
D2: J6.19, U6.35 (D2); also elsewhere on the board
D3: J6.18, U6.34 (D3); also elsewhere on the board
D4: J6.17, U6.33 (D4); also elsewhere on the board
D5: J6.16, U6.32 (D5); also elsewhere on the board
D6: J6.15, U6.31 (D6); also elsewhere on the board
D7: J6.14, U6.30 (D7); also elsewhere on the board
DOTCLK: J6.6; also elsewhere on the board
GND: C7.2, J6.1, J6.22, J6.A, J6.Z, U6.21 (VSS); also elsewhere on the board
unnamed: U3.6, U6.5 (AEC)
unnamed: U3.8, U6.2 (RDY)
PHI0: U6.1 (PHI0); also elsewhere on the board
PHI2: J6.E, U6.39 (PHI2); also elsewhere on the board
R~W: J6.5, RN5.2 (R1), RN5.3 (R2), U6.38 (R/W); also elsewhere on the board
~CHAREN: RN5.7 (R6), U6.27 (P2); also elsewhere on the board
~EXROM: J6.9, RN4.8 (R7); also elsewhere on the board
~GAME: J6.8, RN4.6 (R5); also elsewhere on the board
~HIRAM: RN5.6 (R5), U6.28 (P1); also elsewhere on the board
~INTRES: J6.C, U6.40 (~RES); also elsewhere on the board
~IO1: J6.7; also elsewhere on the board
~IO2: J6.10; also elsewhere on the board
~IRQ: J6.4, RN4.2 (R1), U6.3 (~IRQ); also elsewhere on the board
~LORAM: RN5.4 (R3), U6.29 (P0); also elsewhere on the board
~NMI: J6.D, U6.4 (~NMI); also elsewhere on the board
~ROMH: J6.B; also elsewhere on the board
~ROML: J6.11; also elsewhere on the board

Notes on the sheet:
EXPANSION PORT
EXPANSION
CN6
(44 PIN FEMALE EDGE)
Pull-up resistors
To Memory Controller 251715-01
To Tape
CPU
(DF00-DFFF; DISK)
(DE00-DEFF; Z80 ON)
From Clock Generator

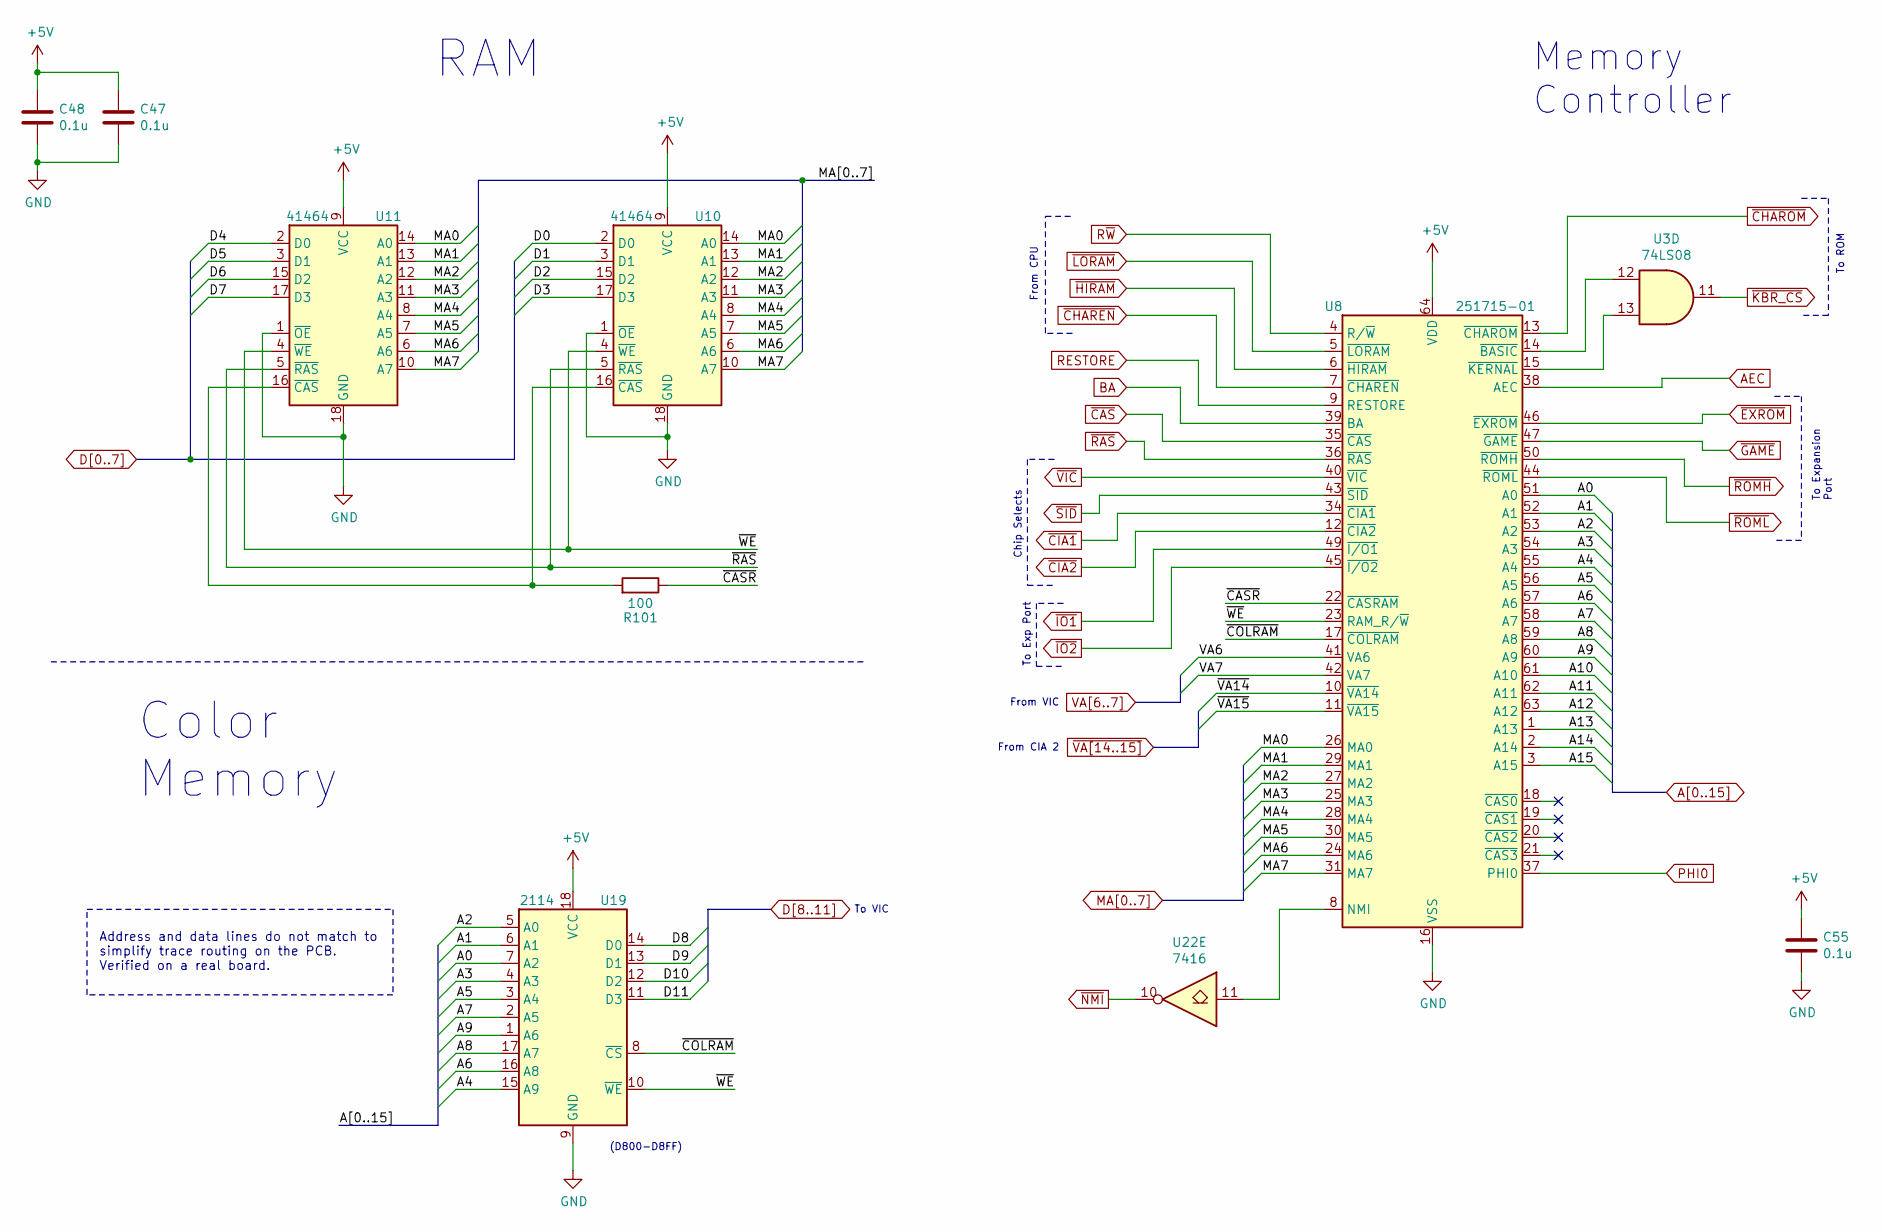
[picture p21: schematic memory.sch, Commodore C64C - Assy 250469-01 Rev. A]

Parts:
C47, C48, C55: 0.1u; C_Disc_D4.7mm_W2.5mm_P5.00mm
R101: 100; R_Axial_DIN0207_L6.3mm_D2.5mm_P5.08mm_Vertical
U3: 74LS08; DIP-14_W7.62mm_Socket
U8: 251715-01; SPDIP-64_W19.05mm_Socket_LongPads
U10, U11: 41464; DIP-18_W7.62mm_Socket
U19: 2114; DIP-18_W7.62mm_Socket
U22: 7416; DIP-14_W7.62mm_Socket

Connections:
+5V: C47.1, C48.1, C55.1, U8.64 (VDD), U10.9 (VCC), U11.9 (VCC), U19.18 (VCC); also elsewhere on the board
/Memory Controller - RAM/~CASR: R101.1, U8.22 (~CASRAM)
/Memory Controller - RAM/~COLRAM: U8.17 (~COLRAM), U19.8 (~CS)
/Memory Controller - RAM/~WE: U8.23 (RAM_R/~W), U10.4 (~WE), U11.4 (~WE), U19.10 (~WE)
A0: U8.51 (A0), U19.7 (A2); also elsewhere on the board
A1: U8.52 (A1), U19.6 (A1); also elsewhere on the board
A2: U8.53 (A2), U19.5 (A0); also elsewhere on the board
A3: U8.54 (A3), U19.4 (A3); also elsewhere on the board
A4: U8.55 (A4), U19.15 (A9); also elsewhere on the board
A5: U8.56 (A5), U19.3 (A4); also elsewhere on the board
A6: U8.57 (A6), U19.16 (A8); also elsewhere on the board
A7: U8.58 (A7), U19.2 (A5); also elsewhere on the board
A8: U8.59 (A8), U19.17 (A7); also elsewhere on the board
A9: U8.60 (A9), U19.1 (A6); also elsewhere on the board
A10: U8.61 (A10); also elsewhere on the board
A11: U8.62 (A11); also elsewhere on the board
A12: U8.63 (A12); also elsewhere on the board
A13: U8.1 (A13); also elsewhere on the board
A14: U8.2 (A14); also elsewhere on the board
A15: U8.3 (A15); also elsewhere on the board
AEC: U8.38 (AEC); also elsewhere on the board
BA: U8.39 (BA); also elsewhere on the board
D0: U10.2 (D0); also elsewhere on the board
D1: U10.3 (D1); also elsewhere on the board
D2: U10.15 (D2); also elsewhere on the board
D3: U10.17 (D3); also elsewhere on the board
D4: U11.2 (D0); also elsewhere on the board
D5: U11.3 (D1); also elsewhere on the board
D6: U11.15 (D2); also elsewhere on the board
D7: U11.17 (D3); also elsewhere on the board
D8: U19.14 (D0); also elsewhere on the board
D9: U19.13 (D1); also elsewhere on the board
D10: U19.12 (D2); also elsewhere on the board
D11: U19.11 (D3); also elsewhere on the board
GND: C47.2, C48.2, C55.2, U8.16 (VSS), U8.33 (VSS), U8.48 (VSS), U10.1 (~OE), U10.18 (GND), U11.1 (~OE), U11.18 (GND), U19.9 (GND); also elsewhere on the board
MA0: U8.26 (MA0), U10.14 (A0), U11.14 (A0); also elsewhere on the board
MA1: U8.29 (MA1), U10.13 (A1), U11.13 (A1); also elsewhere on the board
MA2: U8.27 (MA2), U10.12 (A2), U11.12 (A2); also elsewhere on the board
MA3: U8.25 (MA3), U10.11 (A3), U11.11 (A3); also elsewhere on the board
MA4: U8.28 (MA4), U10.8 (A4), U11.8 (A4); also elsewhere on the board
MA5: U8.30 (MA5), U10.7 (A5), U11.7 (A5); also elsewhere on the board
MA6: U8.24 (MA6), U10.6 (A6), U11.6 (A6)
MA7: U8.31 (MA7), U10.10 (A7), U11.10 (A7)
unnamed: R101.2, U10.16 (~CAS), U11.16 (~CAS)
unnamed: U3.12, U8.14 (~BASIC)
unnamed: U3.13, U8.15 (~KERNAL)
unnamed: U8.8 (NMI), U22.11
PHI0: U8.37 (PHI0); also elsewhere on the board
RESTORE: U8.9 (RESTORE); also elsewhere on the board
R~W: U8.4 (R/~W); also elsewhere on the board
VA6: U8.41 (VA6); also elsewhere on the board
VA7: U8.42 (VA7); also elsewhere on the board
~CAS: U8.35 (~CAS); also elsewhere on the board
~CHAREN: U8.7 (~CHAREN); also elsewhere on the board
~CHAROM: U8.13 (~CHAROM); also elsewhere on the board
~CIA1: U8.34 (~CIA1); also elsewhere on the board
~CIA2: U8.12 (~CIA2); also elsewhere on the board
~EXROM: U8.46 (~EXROM); also elsewhere on the board
~GAME: U8.47 (~GAME); also elsewhere on the board
~HIRAM: U8.6 (~HIRAM); also elsewhere on the board
~IO1: U8.49 (~I/O1); also elsewhere on the board
~IO2: U8.45 (~I/O2); also elsewhere on the board
~KBR_CS: U3.11; also elsewhere on the board
~LORAM: U8.5 (~LORAM); also elsewhere on the board
~NMI: U22.10; also elsewhere on the board
~RAS: U8.36 (~RAS), U10.5 (~RAS), U11.5 (~RAS); also elsewhere on the board
~ROMH: U8.50 (~ROMH); also elsewhere on the board
~ROML: U8.44 (~ROML); also elsewhere on the board
~SID: U8.43 (~SID); also elsewhere on the board
~VA14: U8.10 (~VA14); also elsewhere on the board
~VA15: U8.11 (~VA15); also elsewhere on the board
~VIC: U8.40 (~VIC); also elsewhere on the board

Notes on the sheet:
Chip Selects
To Exp Port
Memory Controller
RAM
Color Memory
(D800-D8FF)
From CPU
To Expansion Port
To ROM
From VIC
From CIA 2
To VIC
Address and data lines do not match to simplify trace routing on the PCB. Verified on a real board.

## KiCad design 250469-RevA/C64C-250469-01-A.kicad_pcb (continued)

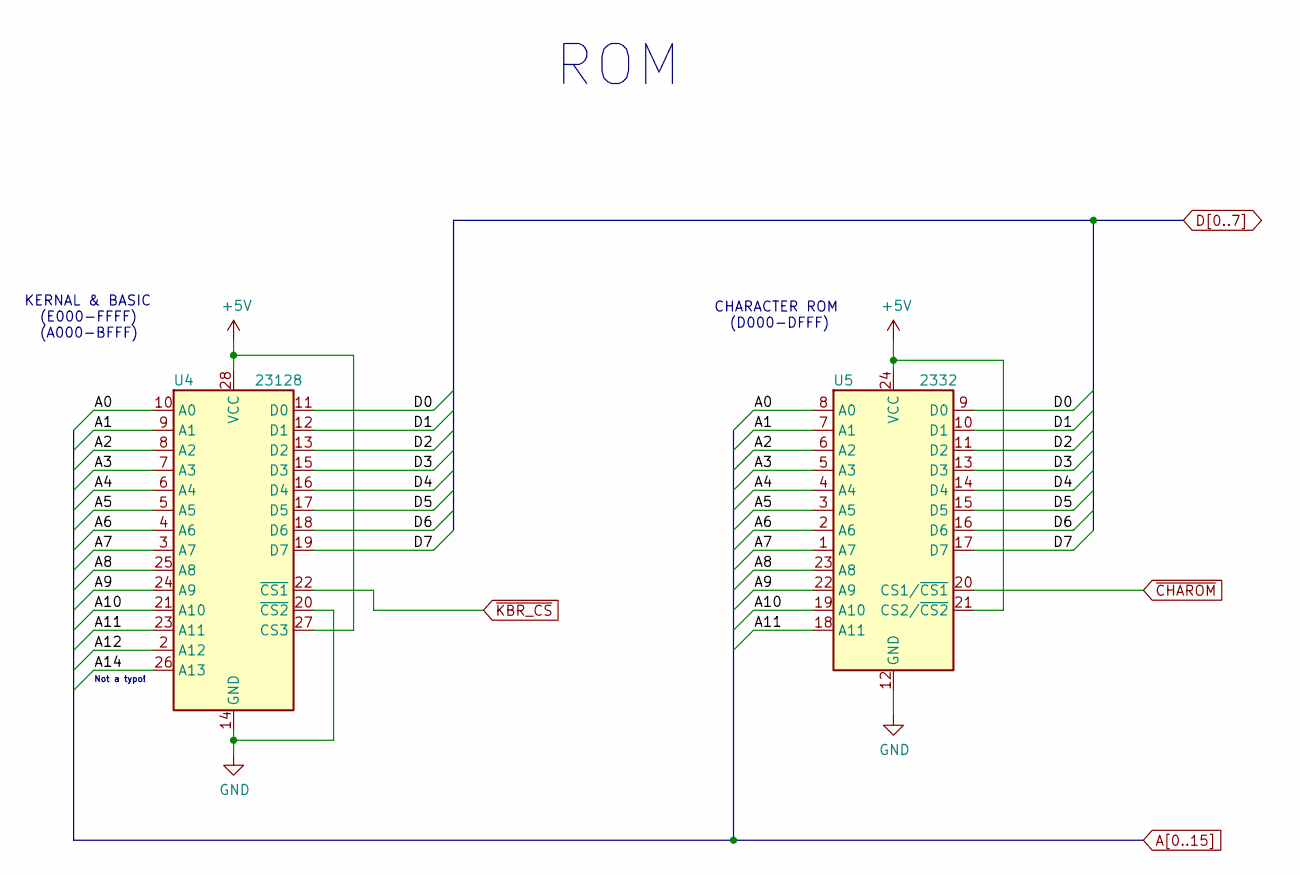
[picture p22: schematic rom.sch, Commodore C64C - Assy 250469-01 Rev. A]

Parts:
U4: 23128; DIP-28_W15.24mm_Socket
U5: 2332; DIP-24_W15.24mm_Socket

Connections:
+5V: U4.27 (CS3), U4.28 (VCC), U5.21 (CS2/~CS2), U5.24 (VCC); also elsewhere on the board
A0: U4.10 (A0), U5.8 (A0); also elsewhere on the board
A1: U4.9 (A1), U5.7 (A1); also elsewhere on the board
A2: U4.8 (A2), U5.6 (A2); also elsewhere on the board
A3: U4.7 (A3), U5.5 (A3); also elsewhere on the board
A4: U4.6 (A4), U5.4 (A4); also elsewhere on the board
A5: U4.5 (A5), U5.3 (A5); also elsewhere on the board
A6: U4.4 (A6), U5.2 (A6); also elsewhere on the board
A7: U4.3 (A7), U5.1 (A7); also elsewhere on the board
A8: U4.25 (A8), U5.23 (A8); also elsewhere on the board
A9: U4.24 (A9), U5.22 (A9); also elsewhere on the board
A10: U4.21 (A10), U5.19 (A10); also elsewhere on the board
A11: U4.23 (A11), U5.18 (A11); also elsewhere on the board
A12: U4.2 (A12); also elsewhere on the board
A14: U4.26 (A13); also elsewhere on the board
D0: U4.11 (D0), U5.9 (D0); also elsewhere on the board
D1: U4.12 (D1), U5.10 (D1); also elsewhere on the board
D2: U4.13 (D2), U5.11 (D2); also elsewhere on the board
D3: U4.15 (D3), U5.13 (D3); also elsewhere on the board
D4: U4.16 (D4), U5.14 (D4); also elsewhere on the board
D5: U4.17 (D5), U5.15 (D5); also elsewhere on the board
D6: U4.18 (D6), U5.16 (D6); also elsewhere on the board
D7: U4.19 (D7), U5.17 (D7); also elsewhere on the board
GND: U4.14 (GND), U4.20 (~CS2), U5.12 (GND); also elsewhere on the board
~CHAROM: U5.20 (CS1/~CS1); also elsewhere on the board
~KBR_CS: U4.22 (~CS1); also elsewhere on the board

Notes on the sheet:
Not a typo!
KERNAL & BASIC (E000-FFFF) (A000-BFFF)
CHARACTER ROM (D000-DFFF)
ROM

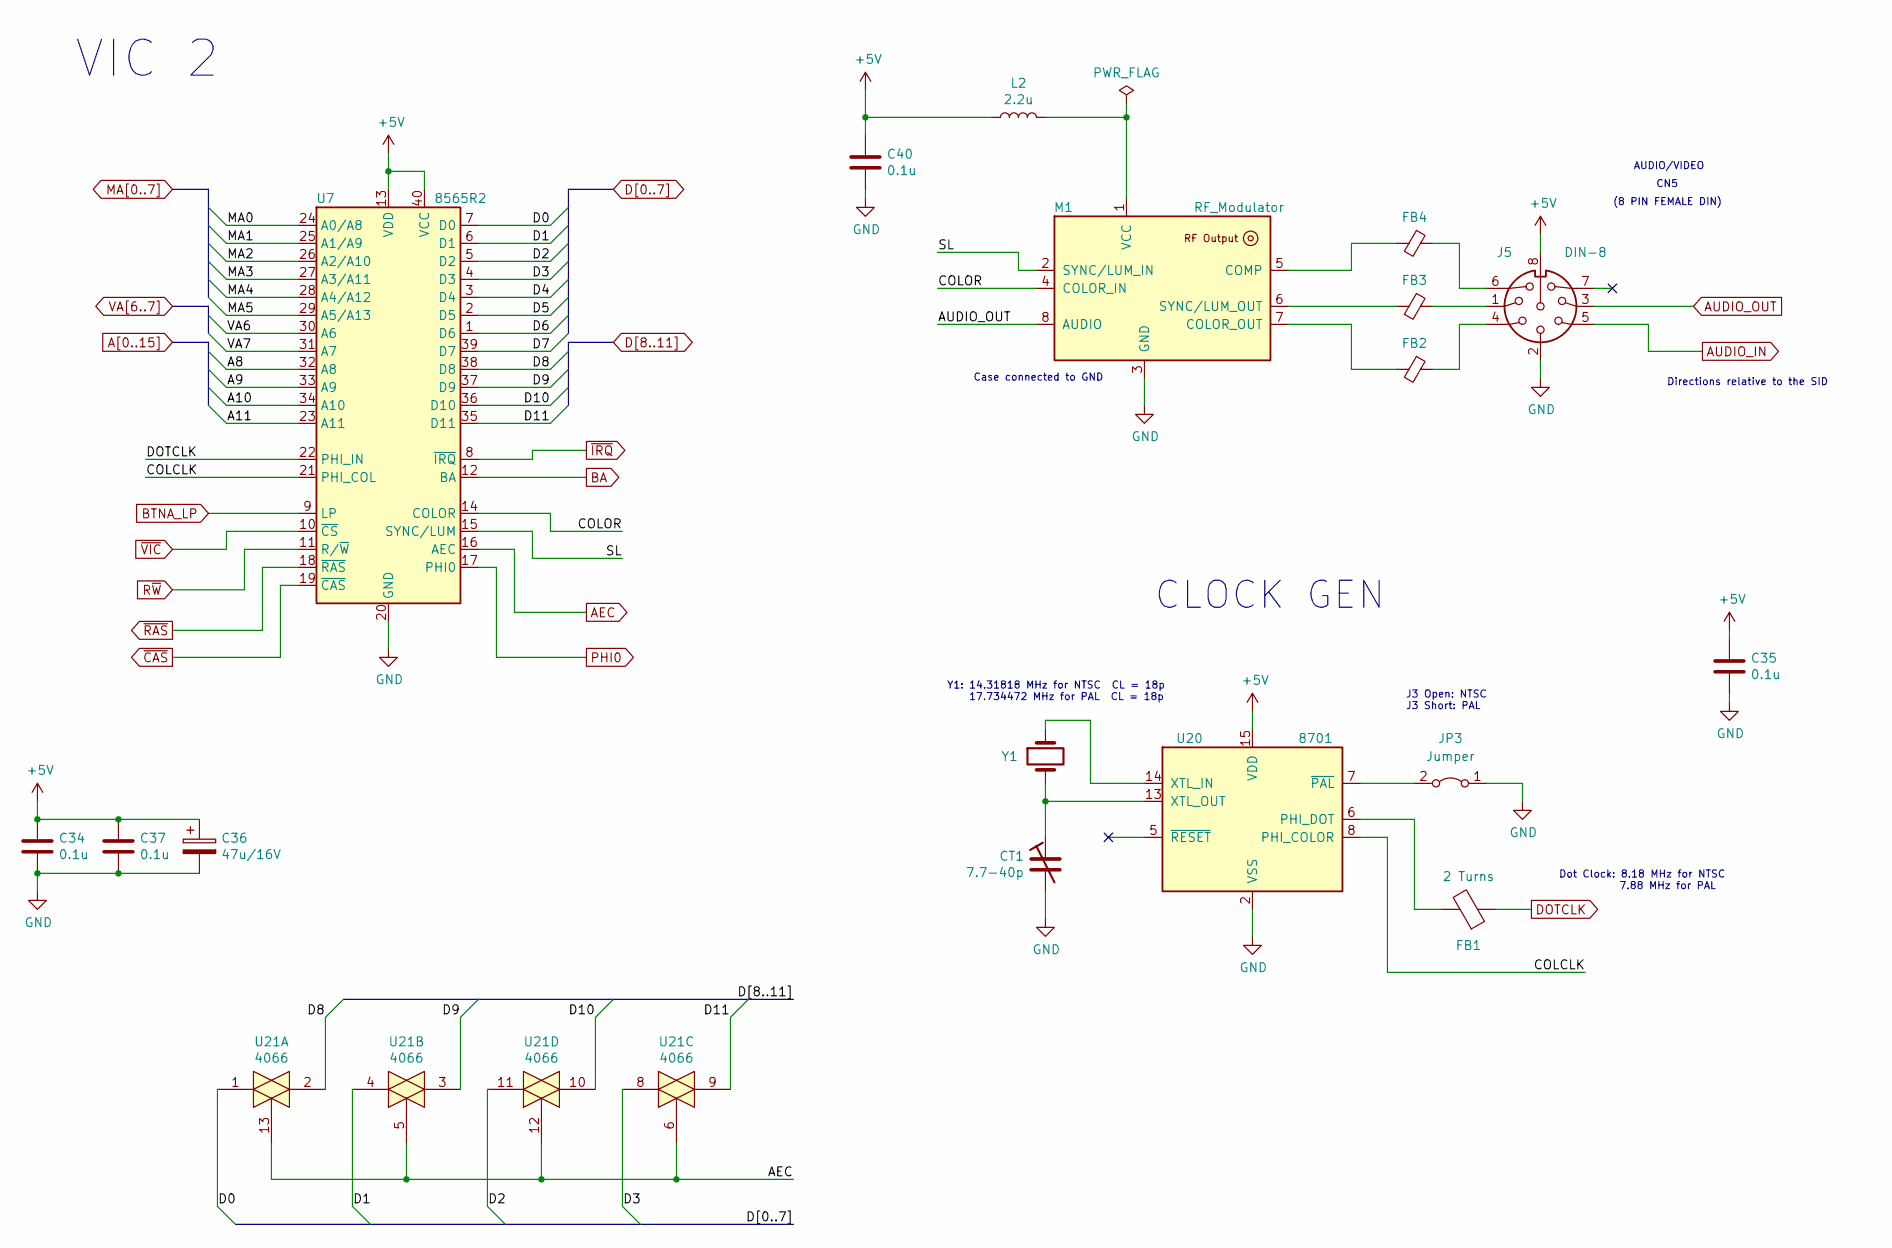
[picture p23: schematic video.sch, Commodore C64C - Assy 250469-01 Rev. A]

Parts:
C34, C35, C37, C40: 0.1u; C_Disc_D4.7mm_W2.5mm_P5.00mm
C36: 47u/16V; CP_Radial_D8.0mm_P5.00mm
CT1: 7.7-40p; C_Trimmer_JML_JML06_P5mm
FB1: 2 Turns; L_Axial_Dual_L7.0mm_D3.3mm_P5.08mm_Vertical
FB2, FB3, FB4: Ferrite_Bead_Small; L_Axial_L7.0mm_D3.3mm_P5.08mm_Vertical_Fastron_MICC
J5: DIN-8; C64_Original_DIN-8_Circular
JP3: Jumper; PinHeader_1x02_P2.54mm_Vertical
L2: 2.2u; L_Axial_L9.5mm_D4.0mm_P15.24mm_Horizontal_Fastron_SMCC
M1: RF_Modulator
U7: 8565R2; DIP-40_W15.24mm_Socket
U20: 8701; DIP-16_W7.62mm_Socket
U21: 4066; DIP-14_W7.62mm_Socket
Y1: Crystal; Crystal_HC49-U_Vertical

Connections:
+5V: C34.1, C35.1, C36.1, C37.1, C40.1, J5.8, L2.1, U7.13 (VDD), U7.40 (VCC), U20.12 (VDD), U20.15 (VDD); also elsewhere on the board
/Video - ClockGen/COLCLK: U7.21 (PHI_COL), U20.8 (PHI_COLOR)
/Video - ClockGen/COLOR: M1.4 (COLOR_IN), U7.14 (COLOR)
/Video - ClockGen/SL: M1.2 (SYNC/LUM_IN), U7.15 (SYNC/LUM)
A8: U7.32 (A8); also elsewhere on the board
A9: U7.33 (A9); also elsewhere on the board
A10: U7.34 (A10); also elsewhere on the board
A11: U7.23 (A11); also elsewhere on the board
AEC: U7.16 (AEC), U21.5, U21.6, U21.12, U21.13; also elsewhere on the board
AUDIO_IN: J5.5; also elsewhere on the board
AUDIO_OUT: J5.3, M1.8 (AUDIO); also elsewhere on the board
BA: U7.12 (BA); also elsewhere on the board
BTNA_LP: U7.9 (LP); also elsewhere on the board
D0: U7.7 (D0), U21.1; also elsewhere on the board
D1: U7.6 (D1), U21.4; also elsewhere on the board
D2: U7.5 (D2), U21.11; also elsewhere on the board
D3: U7.4 (D3), U21.8; also elsewhere on the board
D4: U7.3 (D4); also elsewhere on the board
D5: U7.2 (D5); also elsewhere on the board
D6: U7.1 (D6); also elsewhere on the board
D7: U7.39 (D7); also elsewhere on the board
D8: U7.38 (D8), U21.2; also elsewhere on the board
D9: U7.37 (D9), U21.3; also elsewhere on the board
D10: U7.36 (D10), U21.10; also elsewhere on the board
D11: U7.35 (D11), U21.9; also elsewhere on the board
DOTCLK: FB1.1, U7.22 (PHI_IN); also elsewhere on the board
GND: C34.2, C35.2, C36.2, C37.2, C40.2, CT1.2, J5.0, J5.2, JP3.1 (A), M1.3 (GND), U7.20 (GND), U20.2 (VSS), U20.4, U20.9 (VSS); also elsewhere on the board
MA0: U7.24 (A0/A8); also elsewhere on the board
MA1: U7.25 (A1/A9); also elsewhere on the board
MA2: U7.26 (A2/A10); also elsewhere on the board
MA3: U7.27 (A3/A11); also elsewhere on the board
MA4: U7.28 (A4/A12); also elsewhere on the board
MA5: U7.29 (A5/A13); also elsewhere on the board
unnamed: CT1.1, U20.13 (XTL_OUT), Y1.2
unnamed: FB1.2, U20.6 (PHI_DOT)
unnamed: FB2.1, J5.4
unnamed: FB2.2, M1.7 (COLOR_OUT)
unnamed: FB3.1, J5.1
unnamed: FB3.2, M1.6 (SYNC/LUM_OUT)
unnamed: FB4.1, J5.6
unnamed: FB4.2, M1.5 (COMP)
unnamed: JP3.2 (B), U20.7 (~PAL)
unnamed: L2.2, M1.1 (VCC)
unnamed: U20.14 (XTL_IN), Y1.1
PHI0: U7.17 (PHI0); also elsewhere on the board
R~W: U7.11 (R/~W); also elsewhere on the board
VA6: U7.30 (A6); also elsewhere on the board
VA7: U7.31 (A7); also elsewhere on the board
~CAS: U7.19 (~CAS); also elsewhere on the board
~IRQ: U7.8 (~IRQ); also elsewhere on the board
~RAS: U7.18 (~RAS); also elsewhere on the board
~VIC: U7.10 (~CS); also elsewhere on the board

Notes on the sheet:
Y1: 14.31818 MHz for NTSC CL = 18p 17.734472 MHz for PAL CL = 18p
J3 Open: NTSC J3 Short: PAL
Dot Clock: 8.18 MHz for NTSC 7.88 MHz for PAL
CLOCK GEN
VIC 2
Directions relative to the SID
CN5
(8 PIN FEMALE DIN)
AUDIO/VIDEO
Case connected to GND

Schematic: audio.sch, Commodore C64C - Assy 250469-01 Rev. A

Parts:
C39, C69, C79: 0.1u; C_Disc_D4.7mm_W2.5mm_P5.00mm
C70, C71: 22n; C_Disc_D4.7mm_W2.5mm_P5.00mm
C74: 1000p; C_Disc_D4.7mm_W2.5mm_P5.00mm
C76: 470p; C_Disc_D4.7mm_W2.5mm_P5.00mm
C77: 10u; CP_Radial_D10.0mm_P5.00mm
C80, C81: 2200p; C_Disc_D4.7mm_W2.5mm_P5.00mm
Q3: 2SC1815; TO-92_Inline
R8, R12: 1k; R_Axial_DIN0207_L6.3mm_D2.5mm_P5.08mm_Vertical
R9: 10k; R_Axial_DIN0207_L6.3mm_D2.5mm_P5.08mm_Vertical
R14: 100k; R_Axial_DIN0207_L6.3mm_D2.5mm_P5.08mm_Vertical
U9: 8580R5; DIP-28_W15.24mm_Socket

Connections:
+5V: C69.1, U9.25 (VCC); also elsewhere on the board
+9V: C39.1, Q3.2 (C), U9.28 (VDD); also elsewhere on the board
A0: U9.9 (A0); also elsewhere on the board
A1: U9.10 (A1); also elsewhere on the board
A2: U9.11 (A2); also elsewhere on the board
A3: U9.12 (A3); also elsewhere on the board
A4: U9.13 (A4); also elsewhere on the board
AUDIO_IN: C79.1, R14.1; also elsewhere on the board
AUDIO_OUT: C77.2; also elsewhere on the board
D0: U9.15 (D0); also elsewhere on the board
D1: U9.16 (D1); also elsewhere on the board
D2: U9.17 (D2); also elsewhere on the board
D3: U9.18 (D3); also elsewhere on the board
D4: U9.19 (D4); also elsewhere on the board
D5: U9.20 (D5); also elsewhere on the board
D6: U9.21 (D6); also elsewhere on the board
D7: U9.22 (D7); also elsewhere on the board
GND: C39.2, C69.2, C74.2, C80.2, C81.2, R8.2, R12.2, R14.2, U9.14 (GND); also elsewhere on the board
unnamed: C70.1, U9.1 (CAP1A)
unnamed: C70.2, U9.2 (CAP1B)
unnamed: C71.1, U9.3 (CAP2A)
unnamed: C71.2, U9.4 (CAP2B)
unnamed: C74.1, C76.1, Q3.3 (B), R9.1
unnamed: C76.2, C77.1, Q3.1 (E), R12.1
unnamed: C79.2, U9.26 (EXT_IN)
unnamed: R8.1, R9.2, U9.27 (AUDIO_OUT)
PHI2: U9.6 (PHI2); also elsewhere on the board
POT_X: C80.1, U9.24 (POT_X); also elsewhere on the board
POT_Y: C81.1, U9.23 (POT_Y); also elsewhere on the board
R~W: U9.7 (R/~W); also elsewhere on the board
~INTRES: U9.5 (~RES); also elsewhere on the board
~SID: U9.8 (~CS); also elsewhere on the board

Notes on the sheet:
From the A/V connector
SID
To the A/V connector
R8 resistor should be removed for 8580 SID.
(D400-D7FFF)

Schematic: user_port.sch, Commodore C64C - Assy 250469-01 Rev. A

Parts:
C6, C90: 470p; C_Disc_D4.7mm_W2.5mm_P5.00mm
C28, C29, C30: 0.1u; C_Disc_D4.7mm_W2.5mm_P5.00mm
C43: 220u; CP_Radial_D8.0mm_P5.00mm
C86, C87, C88: 220p; C_Disc_D4.7mm_W2.5mm_P5.00mm
D5: 1N914; D_DO-35_SOD27_P5.08mm_Vertical_KathodeUp
J2: Conn_02x12_Edge; Connector_Edge_2x12_P3.96mm
RN3: 3.3k; R_Array_SIP8
RN6: 1k; R_Array_SIP6
U2: 6526A; DIP-40_W15.24mm_Socket
U22: 7416; DIP-14_W7.62mm_Socket
U23: 74LS14; DIP-14_W7.62mm_Socket

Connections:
9V_AC1: C28.1, J2.10; also elsewhere on the board
9V_AC2: C29.1, J2.11; also elsewhere on the board
+5V: C30.1, D5.1 (K), J2.2, RN3.1 (common), RN6.1 (common), U2.20 (VCC); also elsewhere on the board
/User Port - CIA 2/ATNOUT: U2.5 (PA3), U22.9
/User Port - CIA 2/CLKOUT: U2.6 (PA4), U22.3
/User Port - CIA 2/CNT2: J2.6, RN3.7 (R6), U2.40 (CNT)
/User Port - CIA 2/DATAOUT: U2.7 (PA5), U22.13
/User Port - CIA 2/PA2: J2.M, U2.4 (PA2)
/User Port - CIA 2/PB0: J2.C, U2.10 (PB0)
/User Port - CIA 2/PB1: J2.D, U2.11 (PB1)
/User Port - CIA 2/PB2: J2.E, U2.12 (PB2)
/User Port - CIA 2/PB3: J2.F, U2.13 (PB3)
/User Port - CIA 2/PB4: J2.H, U2.14 (PB4)
/User Port - CIA 2/PB5: J2.J, U2.15 (PB5)
/User Port - CIA 2/PB6: J2.K, U2.16 (PB6)
/User Port - CIA 2/PB7: J2.L, U2.17 (PB7)
/User Port - CIA 2/SP2: J2.7, RN3.8 (R7), U2.39 (SP)
/User Port - CIA 2/~FLAG_2: C6.1, J2.B, RN3.4 (R3), U2.24 (~FLAG)
/User Port - CIA 2/~PC2: J2.8, U2.18 (~PC)
A0: U2.38 (RS0); also elsewhere on the board
A1: U2.37 (RS1); also elsewhere on the board
A2: U2.36 (RS2); also elsewhere on the board
A3: U2.35 (RS3); also elsewhere on the board
ATN: C88.1, J2.9, RN6.2 (R1), U22.8; also elsewhere on the board
CLK: RN6.6 (R5), U2.8 (PA6), U22.4; also elsewhere on the board
CNT1: C86.1, J2.4, RN3.5 (R4); also elsewhere on the board
D0: U2.33 (DB0); also elsewhere on the board
D1: U2.32 (DB1); also elsewhere on the board
D2: U2.31 (DB2); also elsewhere on the board
D3: U2.30 (DB3); also elsewhere on the board
D4: U2.29 (DB4); also elsewhere on the board
D5: U2.28 (DB5); also elsewhere on the board
D6: U2.27 (DB6); also elsewhere on the board
D7: U2.26 (DB7); also elsewhere on the board
DATA: RN6.4 (R3), U2.9 (PA7), U22.12; also elsewhere on the board
GND: C6.2, C28.2, C29.2, C30.2, C43.2, C86.2, C87.2, C88.2, C90.2, J2.1, J2.12, J2.A, J2.N, U2.1 (GND); also elsewhere on the board
unnamed: C43.1, D5.2 (A), RN3.3 (R2), U23.5
unnamed: U22.1, U22.5, U23.6
PHI2: U2.25 (PHI2); also elsewhere on the board
R~W: U2.22 (R/W); also elsewhere on the board
SP1: C87.1, J2.5, RN3.6 (R5); also elsewhere on the board
TOD: U2.19 (TOD); also elsewhere on the board
~CIA2: U2.23 (~CS); also elsewhere on the board
~EXTRST: RN6.5 (R4), U22.6; also elsewhere on the board
~INTRES: C90.1, J2.3, RN6.3 (R2), U2.34 (~RES), U22.2; also elsewhere on the board
~NMI: RN3.2 (R1), U2.21 (~IRQ); also elsewhere on the board
~VA14: U2.2 (PA0); also elsewhere on the board
~VA15: U2.3 (PA1); also elsewhere on the board

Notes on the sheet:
USER PORT
CN2
(24 PIN MALE EDGE)
(DD00-DDFF)
CIA 2
Low 4 bits of the CPU's address bus
To Serial Port
To Memory Controller 251715-01
From Memory Controller 251715-01
Shared with CIA 1
From CPU
From Exp
To Serial Port

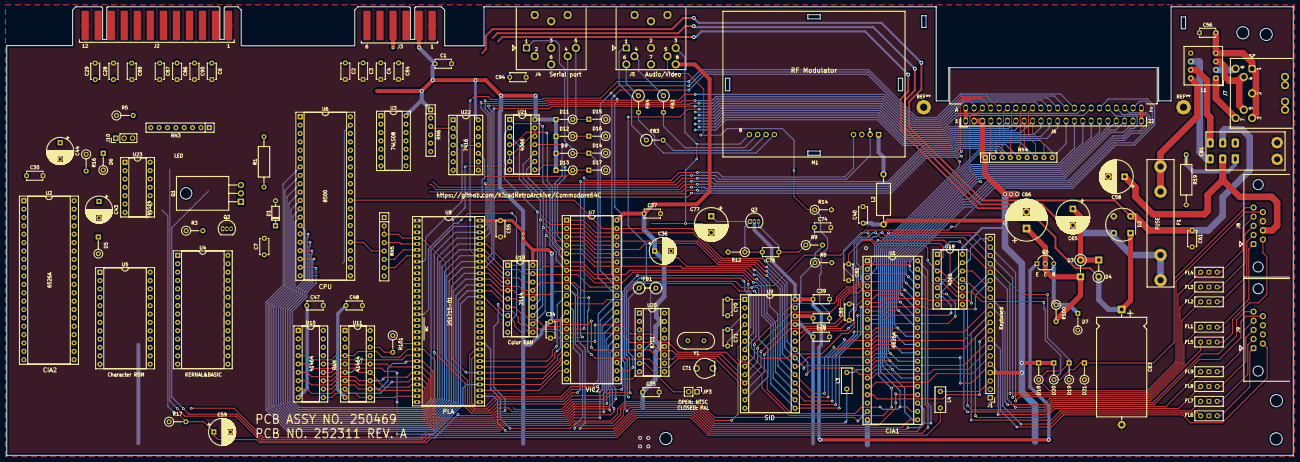
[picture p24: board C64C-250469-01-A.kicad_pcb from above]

Board: 2 copper layers, 390.6 x 136.2 mm, 131 parts (0 on the bottom side), 187 nets.

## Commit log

2020-04-18 Add schematics and libraries
    [C64C-250469-01-A.sch, audio.sch, cpu.sch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]
2020-04-20 Add Kemet SBT-02 choke coil footprints
2020-04-20 Updates and BOMs
    [C64C-250469-01-A.csv, C64C-250469-01-A.ods, C64C-250469-01-A.sch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]
2020-04-26 Add initial PCB with placed components
    [C64C-250469-01-A.csv, C64C-250469-01-A.kicad_pcb, C64C-250469-01-A.ods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]
2020-04-29 Add some artwork to the PCB
    [C64C-250469-01-A.kicad_pcb]
2020-05-02 Add PDF version of the schematic
2020-05-02 Improved edge connectors
    [C64C-250469-01-A.kicad_pcb]
2020-05-02 More work on the PCB
    [C64C-250469-01-A.kicad_pcb]
2020-05-03 Pull changes to the KRL
    [rom.sch]
2020-05-07 PCB: Add some more silkscreen labels
    [C64C-250469-01-A.kicad_pcb]
2020-05-09 Various improvements and changes to footprints
    [C64C-250469-01-A.csv, C64C-250469-01-A.kicad_pcb, C64C-250469-01-A.ods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]
2020-05-10 Change footprint of PLA to Socket version
    [C64C-250469-01-A.csv, C64C-250469-01-A.kicad_pcb, memory.sch]
2020-05-13 Update PDF of schematic
2020-05-13 Change label in Power section
    [power.sch]
2020-05-16 Modified the edge connectors after measuring the originals
2020-05-16 Corrected board dimensions and connector placements
    The dimensions are now 100% correct after carefully measuring
    a real board I acquired a few days ago.
    [C64C-250469-01-A.kicad_pcb]
2020-05-17 Placed all mounting holes on the PCB
    [C64C-250469-01-A.kicad_pcb]
2020-05-21 Changes after updates in the KRL
    [power.sch, tape_serial.sch]
2020-05-21 Right side routed
    [C64C-250469-01-A.kicad_pcb, power.sch]
2020-05-23 Fixed RF Modulator footprint and added 3D model
    [C64C-250469-01-A.kicad_pcb]
2020-05-25 Make pads of expansion connector thinner
2020-05-25 Routed rightmost side of the board
    [C64C-250469-01-A.kicad_pcb]
2020-06-02 More routing around CIA 1
    [C64C-250469-01-A.kicad_pcb]
2020-06-14 Changed footprint of DIC connectors and wiring of Color RAM
    [C64C-250469-01-A.kicad_pcb, memory.sch, power.sch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]
2020-07-12 Minor changes to the memory sheet
    [memory.sch]
2020-07-12 More routing around the memory controller
    [C64C-250469-01-A.kicad_pcb]
2020-09-27 Update schematic after changes in libs
    [audio.sch, joystick.sch, keyboard.sch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]
2020-09-27 More routing
    [C64C-250469-01-A.kicad_pcb]
2021-11-08 Update README.md
    https://forum.kicad.info/t/warning-avoid-all-links-to-kicad-pcb-org-use-kicad-org/31521
